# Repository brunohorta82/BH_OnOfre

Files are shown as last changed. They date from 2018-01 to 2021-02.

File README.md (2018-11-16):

# BH OnOfre
 
* [Intro](#id1)
* [Hardware](#id2)
* [Firmware](https://github.com/brunohorta82/easy_iot)
* [Video Tutoriais - YouTube](https://www.youtube.com/watch?v=OZenBfHWtak&list=PLxDLawCWayzDqAgOpIDJ-DHFAXYd_S-pr)
* [Donativos](#id6)
* [Site Oficial](http://bhonofre.pt/)

## Intro 
O projeto BH OnOfre, é uma solução IoT baseada em ESP8266 com o objetivo de tornar a automação domiciliar muito mais simples, de forma aberta e sem restrições. Todo o código fonte é aberto bem como Hardware.

**BH OnOfre Easy Light** é um dispositivo baseado em ESP8266 com 2 relés de estado sólido cada um de 2A, este permite controlar até 2 circuitos de iluminação independentes. O facto de possuir relés de estado sólido permite ligar e desligar luzes de forma silênciosa.
O OnOfre pode ser instalado atrás dos interruptores normais, possui conectores para ligar o interruptor normal, ou sensor touch. Para alem dos conectores dedicados, permite ainda ligar os mais diversos sensores/atuadores aos GPIO's disponiveis. 
O controlo do mesmo pode ser efectuado via Web, MQTT ou manualmente pelo interruptor, tem integração automatica com o Home Assistant.
Mais info em [Easy Light REPO](https://github.com/brunohorta82/BH_OnOfre/tree/master/OnOfre%20EasyLight)

## Bibliotecas necessárias 

Nome | Link | Versão 
:---: | :---: | ---:
JustWifi | [GIT](https://github.com/xoseperez/justwifi) | `last`
Timming | [GIT](https://github.com/scargill/Timing) | `last`
Async Mqtt Client | [GIT](https://github.com/marvinroger/async-mqtt-client) | `last`
ESP Async TCP | [GIT](https://github.com/me-no-dev/ESPAsyncTCP)| `last`
ESP Async Webserver | [GIT](https://github.com/me-no-dev/ESPAsyncWebServer) | `last`
Bounce2 | [GIT](https://github.com/thomasfredericks/Bounce2) | `last`
DHT Async | [GIT](https://github.com/brunohorta82/DHT_nonblocking) | `last`
Arduino Json | [ARDUINO IDE](https://arduinojson.org) | `5.*`

## Painel de Controlo 

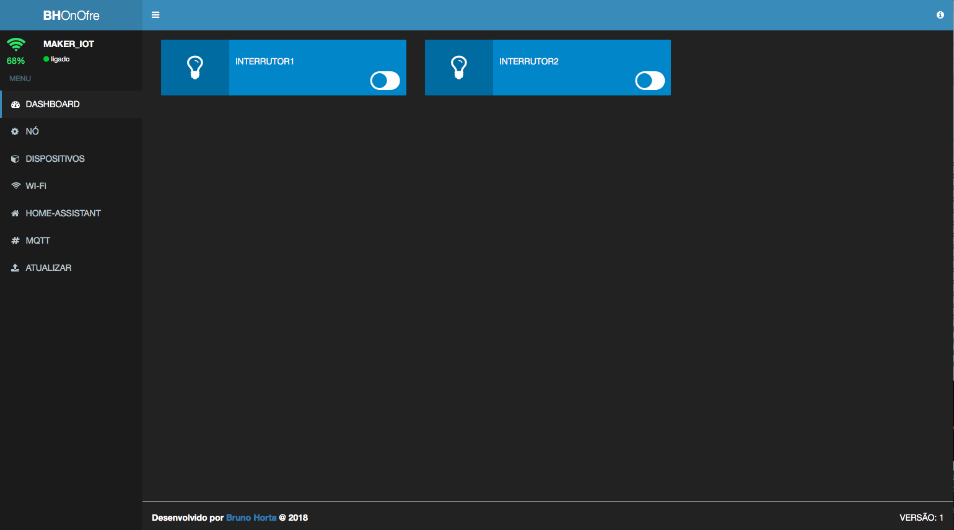
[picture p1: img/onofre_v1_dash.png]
dash

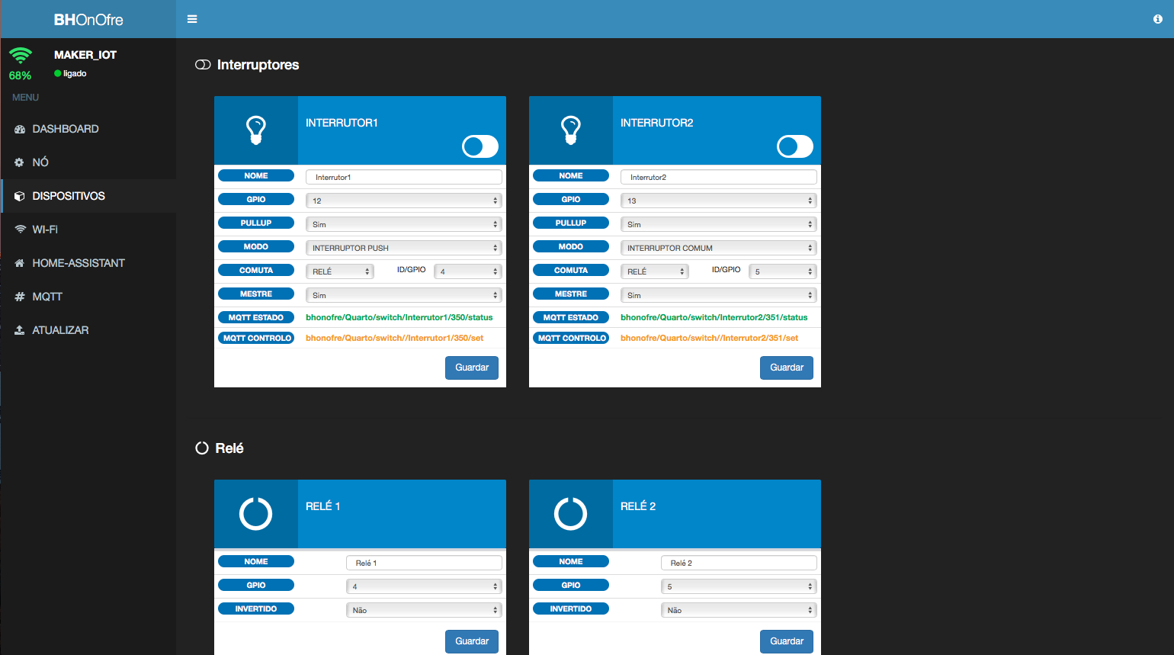
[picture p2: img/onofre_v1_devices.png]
devices


## Hardware 
* BH OnOfre Dev Board 3.4
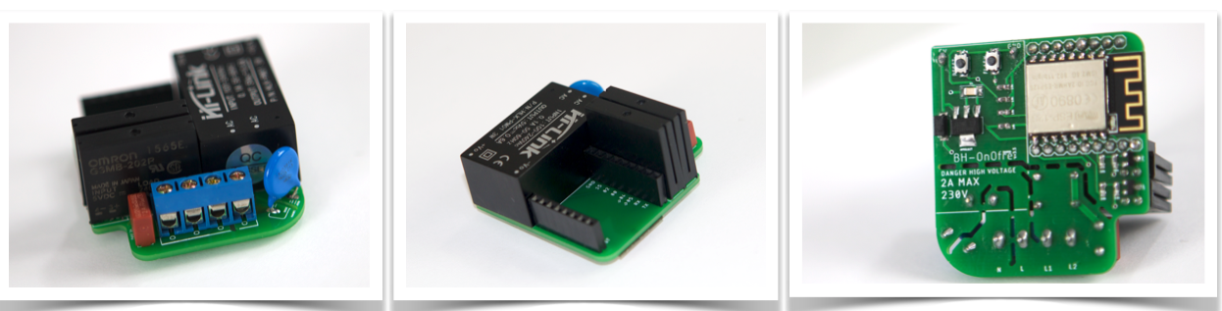
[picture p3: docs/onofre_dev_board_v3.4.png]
dev_board_3.4


## Software necessário 

- Arduino Ide (caso seja para alterar o codigo fonte)
- Upload do Firmware para o ESP8266 (dentro de cada projeto o firmware está dentro da pasta binarios)
- Aceder ao AP `SSID:BH_ONFFRE_NODE_ID` e configurar a Rede Wi-Fi
- Navegar até  `http://<bh-onofre name>.local` ou `http://<bh-onofre IP address>` ou `http://192.168.4.1` ligado directamente ao módulo
- Configurar o `Wi-Fi broker`, `MQTT broker` entre outras coisas como integração automática com `Home Assistant`
- E tá feito, agora é só curtir :) 

## Caixas e Adaptadores
 - [Onofre Livolo Powered by Michaël Memeteau](https://cad.onshape.com/documents/edaf7fef18d999cab7aa6aff/w/efbde367d3f13fc563e8fda8/e/a555c81f28f9aefdf7ebc964)
 - [Onofre Protecção Eléctrica Powered by Bruno Horta](https://cad.onshape.com/documents/2658804f4fec38f38b567684/w/01661975a7b4ba3d280e6216/e/88d1bd909d651dac55006571)

## Donativos 

Se gostaste do projeto podes fazer o teu donativo :).



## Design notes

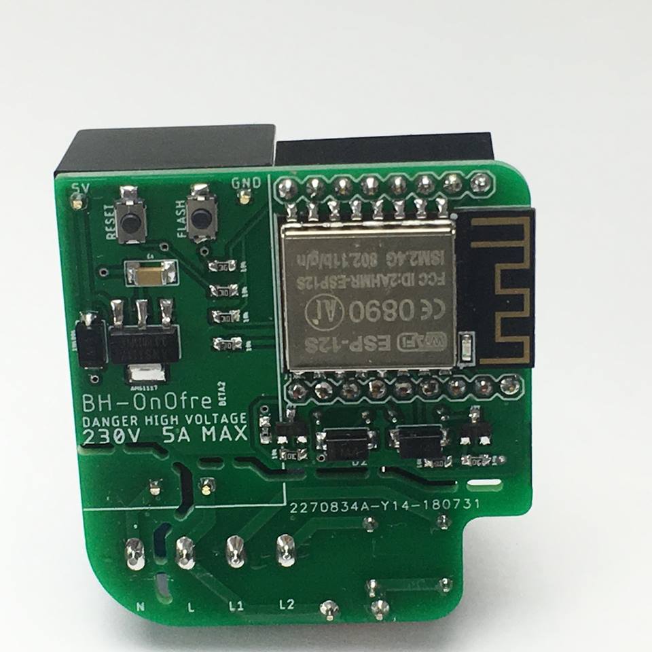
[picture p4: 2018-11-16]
docs/Onofre_5A_beta2_btm.jpg

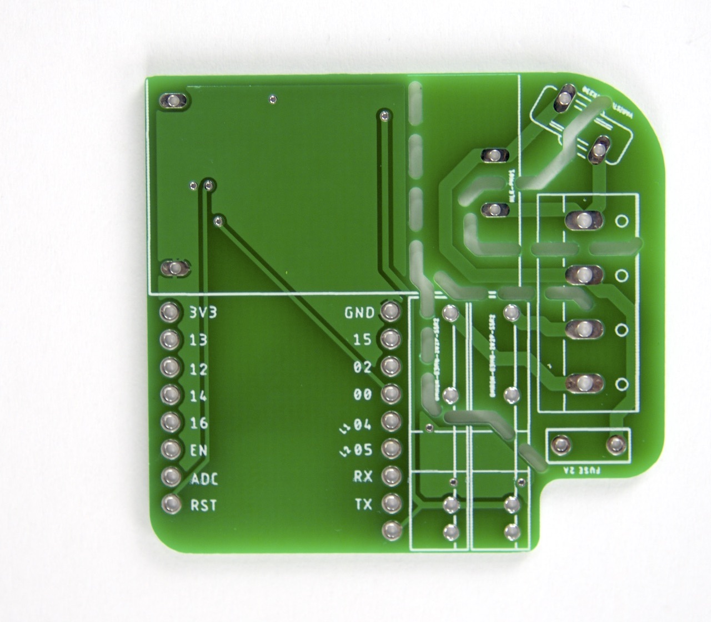
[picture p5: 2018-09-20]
docs/OnOfre_Dev_Board_Rev4.0_02.jpg

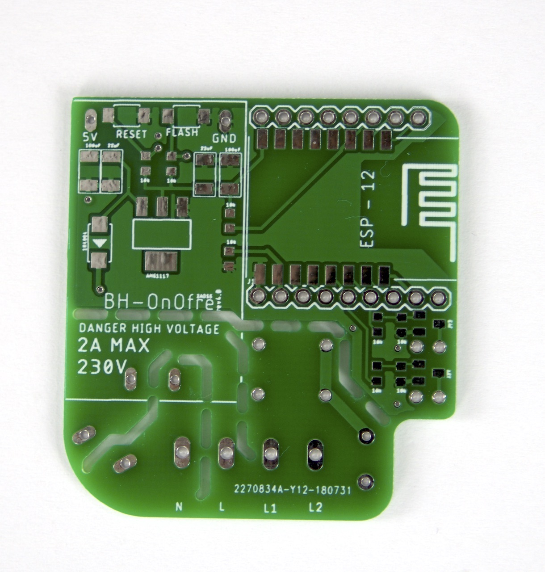
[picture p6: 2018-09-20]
docs/OnOfre_Dev_Board_Rev4.0_01.jpg

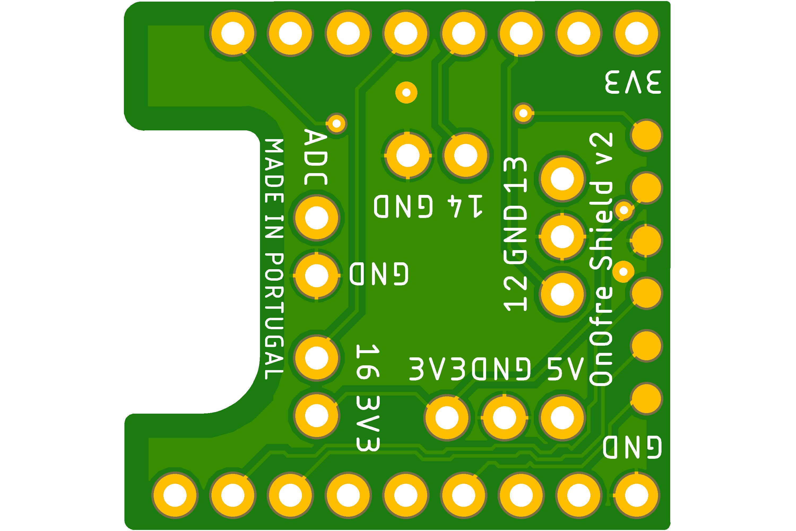
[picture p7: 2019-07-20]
PCB/ONOFRE_WIRE_SHIELD_v2/ONOFRE_WIRE_SHIELD_BTM.png

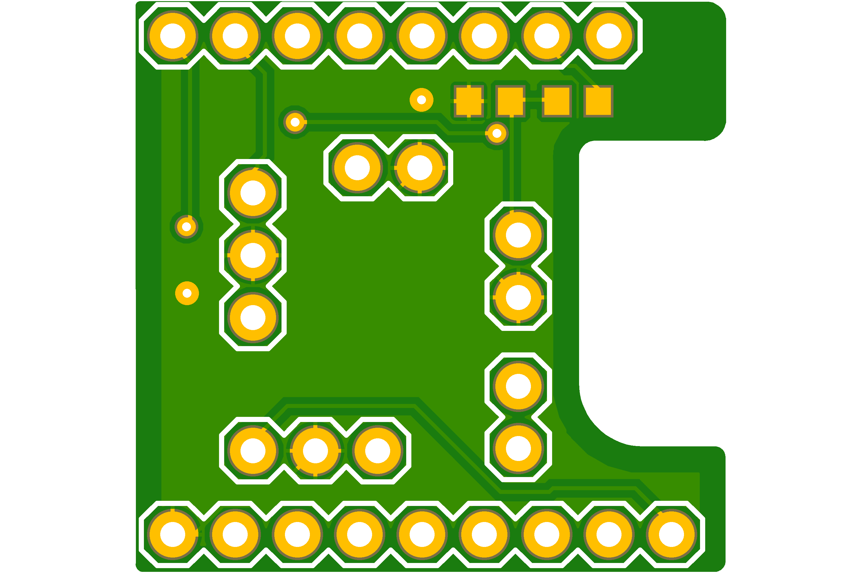
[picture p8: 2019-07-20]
PCB/ONOFRE_WIRE_SHIELD_v2/ONOFRE_WIRE_SHIELD_TOP.png

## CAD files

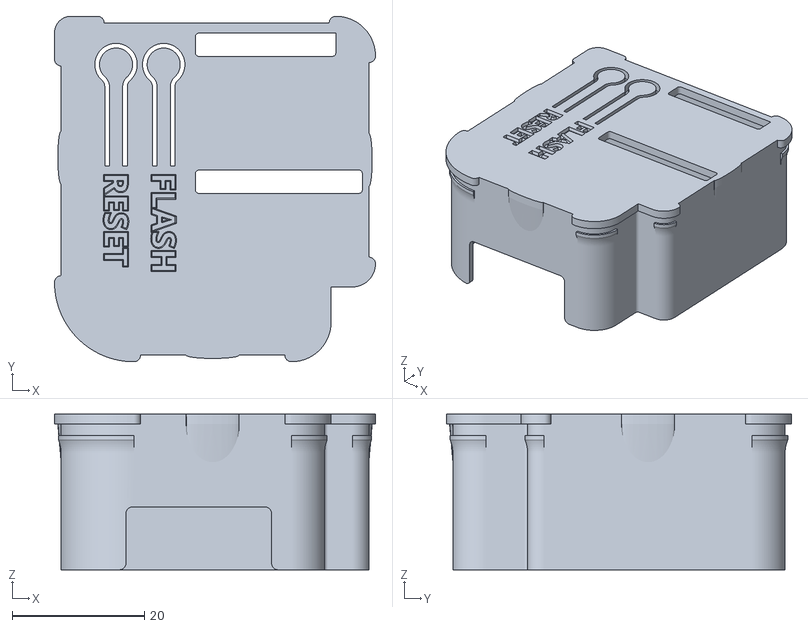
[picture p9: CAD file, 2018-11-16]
CAIXAS_CASES/Onofre Livolo/3D Printed BH Casing Livolo - Casing.stl
48.5 x 52.2 x 23.5

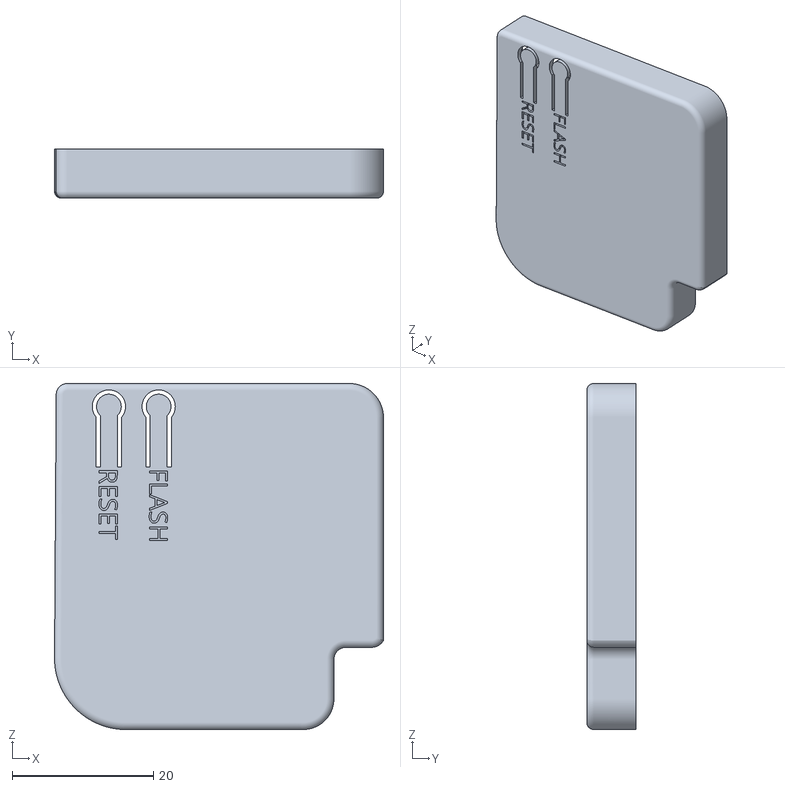
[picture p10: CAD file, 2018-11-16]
CAIXAS_CASES/Onofre Prot/Onofre Protecção.stl
46.6 x 7.00 x 49.0

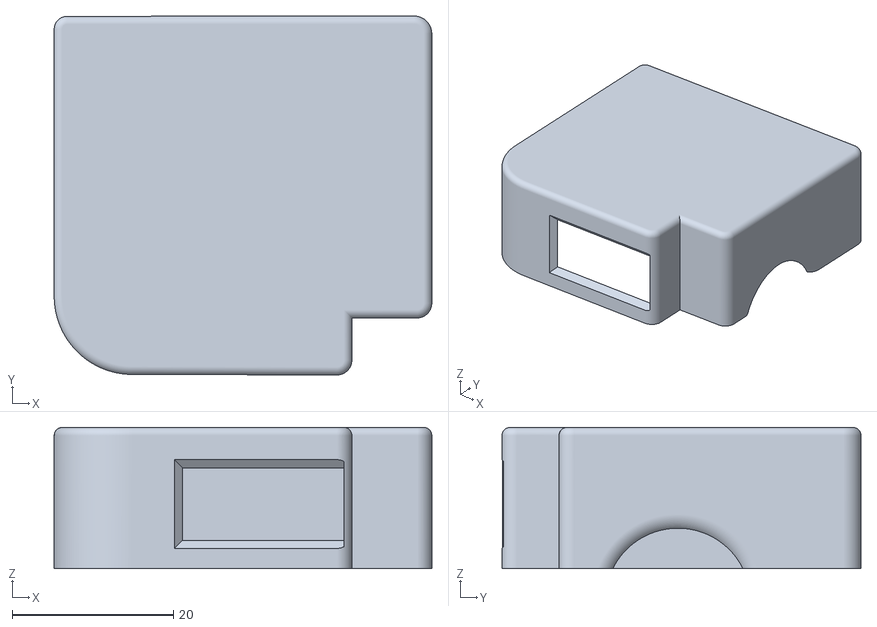
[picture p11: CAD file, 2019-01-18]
CAIXAS_CASES/Onofre Rev5/ONOFRE REV5.stl
46.8 x 44.5 x 17.5

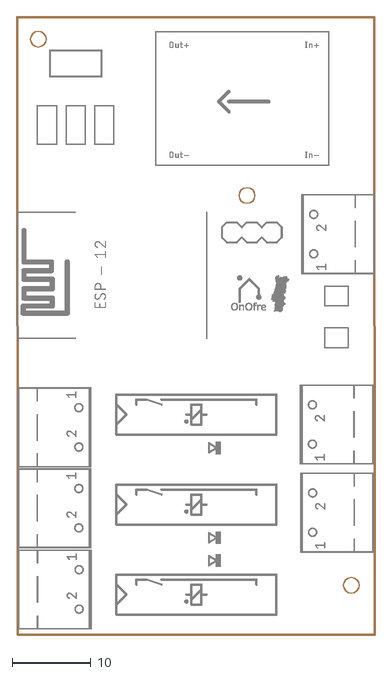
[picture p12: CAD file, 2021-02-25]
PCB/ONOFRE GATE/gate.dxf
45.7 x 78.6

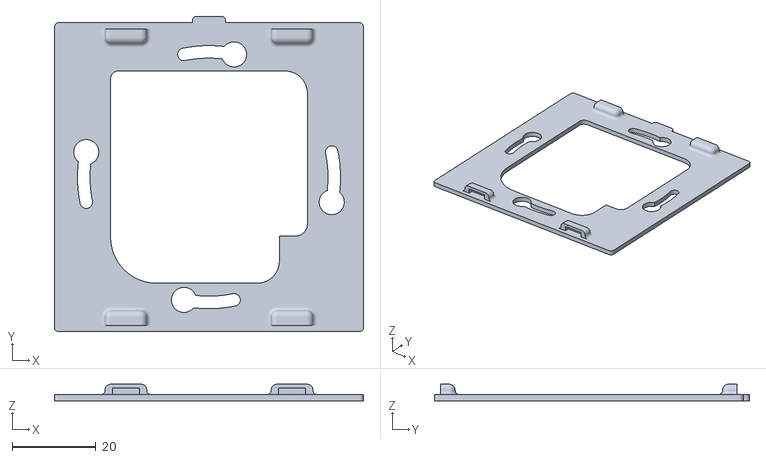
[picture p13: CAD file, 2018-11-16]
CAIXAS_CASES/Onofre Livolo/3D Printed BH Casing Livolo- Plate.stl
74.0 x 75.5 x 4.00

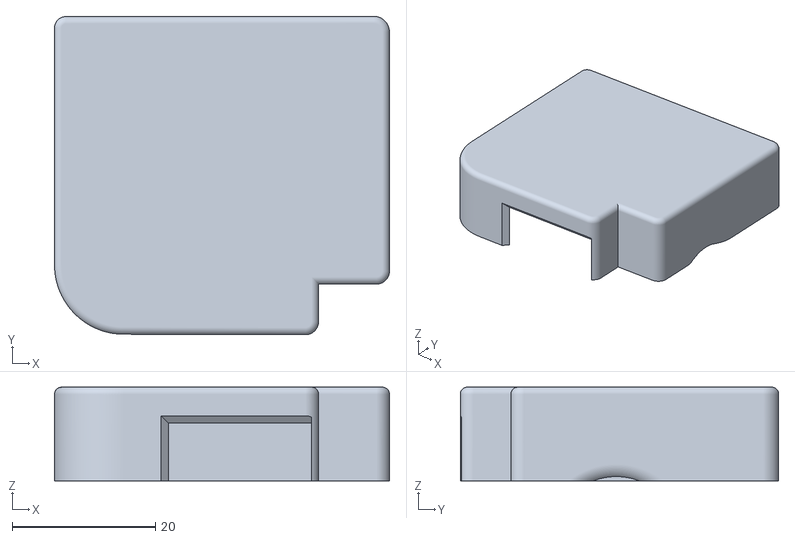
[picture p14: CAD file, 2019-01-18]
CAIXAS_CASES/Onofre Rev5/ONOFRE Bottom Cover REV5.stl
46.8 x 44.5 x 13.1

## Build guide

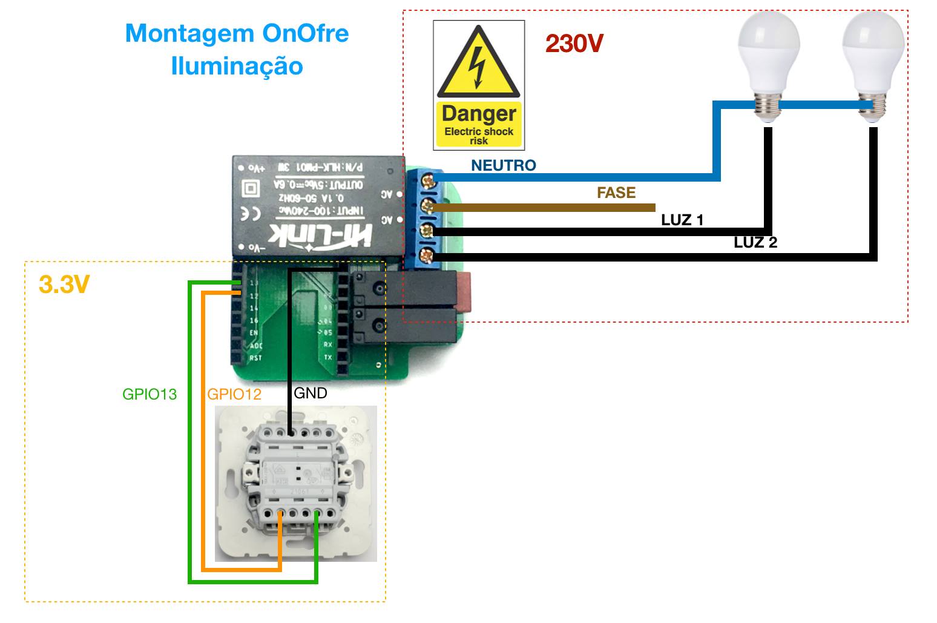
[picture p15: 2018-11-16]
docs/Montagem com iluminação.jpg

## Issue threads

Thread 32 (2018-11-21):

Controlo SSR

LuisCRSousa, 2018-11-21:
Pelo circuito estás a guiar-te pelo hFE do transistor e pelo drop em D3 para definir a corrente do LED, o que é uma má pratica e pode dar maus resultados.

O hFE muda drasticamente em diferentes batchs, temperaturas etc e muito facilmente colocas o LED com o dobro da corrente ou mais.

Recomendações
- Coloca o transistor a funcionar em modo saturação
- Adiciona resistência em série ao LED do SSR para definir a tua corrente e considera Vce=0
- Eliminar D3
- Podes eliminar R2 e R3
- Calcular novos valor de R1 para saturar o transistor

brunohorta82, 2018-11-21:
Olá Luis, obrigado pelos concelhos, na Rev5 já tinha retirado o D3, agora em relação as resistências sendo apenas uma em Serie para cada relé não terei problemas em ter 2 transistores em paralelo sem as resistências de pullup/pulldown?
Já agora que valores recomendas?

Em relação a  maus resultados não tem acontecido em testes de usabilidade diária com mais de ano e meio de uso

LuisCRSousa, 2018-11-21:
Se o GPIO04 e 05 nunca estiverem em alta impedância não há qualquer problema em retirar a R3 e R4. Caso contrário, ou como garantia, podes deixar.

Para a resistência em série com cada LED pode ser uma de 400R o que coloca no máximo uma corrente de 10mA e já fica protegido para qualquer situação estranha como hFE.

Para as R3, R4, R2 e R1 , fiz os cálculos com os valores que já tens e até nem é preciso tocar. Esses valores coloca uma corrente de 0.3mA pela base dos transistors, e com o hFE mínimo definido pelo datasheet, e impõe uma corrente 12mA no coletor. Como a nova resistência de 400 impõe no máximo 10mA ficas garantido para qualquer variação do hFE.

Uma boa prática é calcular o circuito com o hFE para os piores/melhores casos. Com a resistência de 400R garantes que por muito que o hFE aumente, a corrente do LED tem o máximo de 10mA.

brunohorta82, 2018-11-21:
Ok então recomendas 400R no LED do SSR :), Oki, vou colocar

LuisCRSousa, 2018-11-22:
Sim :)

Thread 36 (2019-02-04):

Interrutor vs Interruptor

Ironicster, 2019-02-04:
`     switchJson(id1,SWITCH_ONE,0,0,RELAY_TYPE,RELAY_ONE,0,0,INIT_STATE_OFF,  "Interruptor1", BUTTON_SET_PULLUP,INIT_STATE_OFF,  BUTTON_SWITCH, BUTTON_MASTER, MQTT_STATE_TOPIC_BUILDER(id1,SWITCH_DEVICE,"Interrutor1"), MQTT_COMMAND_TOPIC_BUILDER(id1,SWITCH_DEVICE,"Interruptor1"), "light");
      switchJson(id2,SWITCH_TWO,0,0,RELAY_TYPE,RELAY_TWO,0,0, INIT_STATE_OFF, "Interruptor2", BUTTON_SET_PULLUP,INIT_STATE_OFF,  BUTTON_SWITCH, BUTTON_MASTER, MQTT_STATE_TOPIC_BUILDER(id2,SWITCH_DEVICE,"Interrutor2"),MQTT_COMMAND_TOPIC_BUILDER(id2,SWITCH_DEVICE,"Interruptor2"), "light");`

LInha 447 do Switches.ino
Está Interrutor em vez de Interruptor.
Engano?

brunohorta82, 2019-07-07:
PT: Obrigado está corrigido :)
EN: thanks I already fix that :)

Closed 2019-07-07.

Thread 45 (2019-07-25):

Any plans to make one with 3 relays?

hobojoe, 2019-07-25:
Hi, first of all, great project! Really well done!

I would like to know if you have any plans to make a similar board with 3 relays?

It would be very good for places such as Brazil, where we have 3 switches in 1 gang box.

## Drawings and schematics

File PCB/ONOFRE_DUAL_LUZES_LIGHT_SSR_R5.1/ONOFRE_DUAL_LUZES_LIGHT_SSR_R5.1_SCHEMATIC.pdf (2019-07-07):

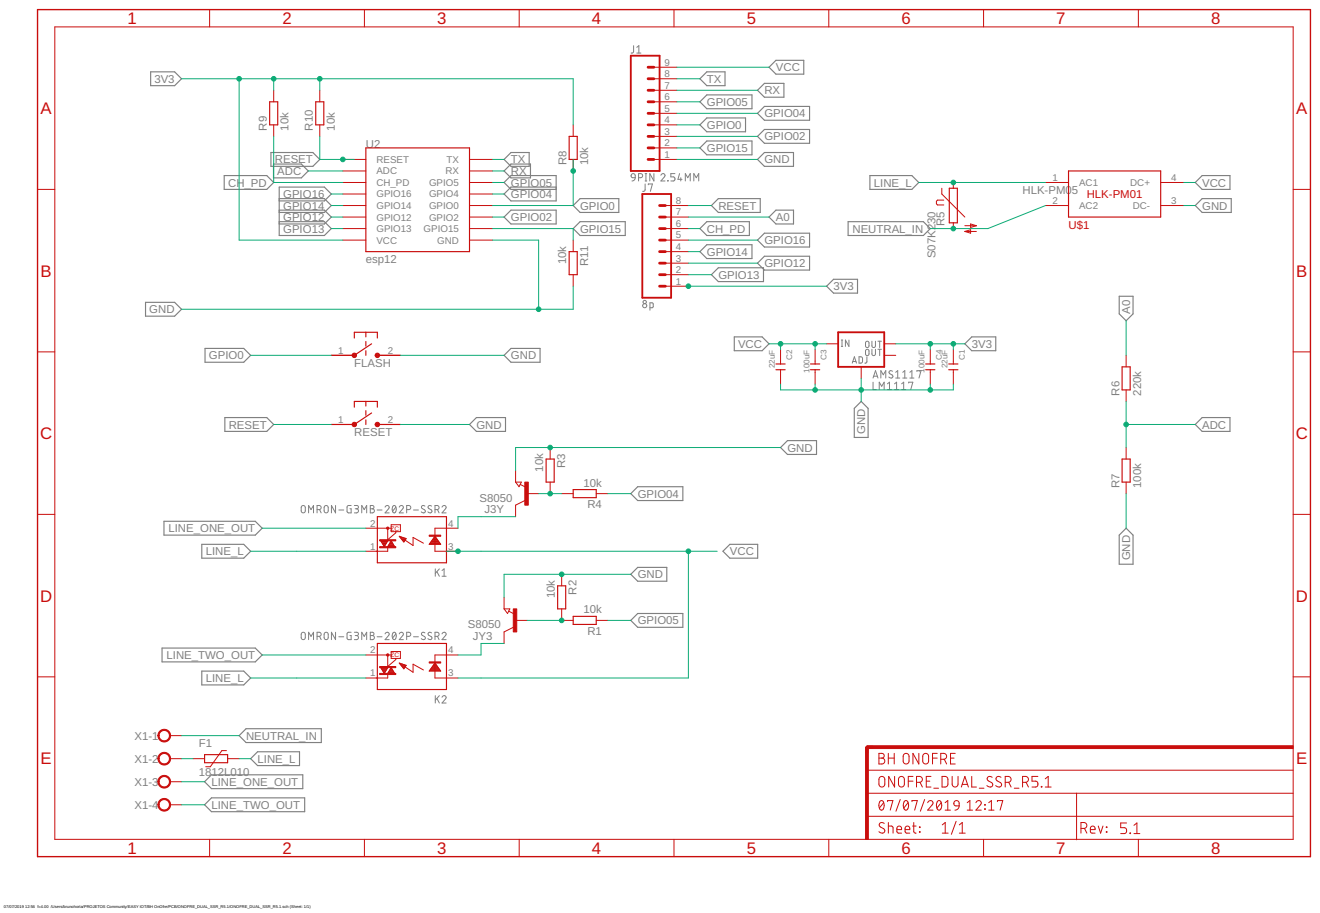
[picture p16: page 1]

07/07/2019 12:56 f=4.00 /Users/brunohorta/PROJETOS Community/EASY IOT/BH OnOfre/PCB/ONOFRE_DUAL_SSR_R5.1/ONOFRE_DUAL_SSR_R5.1.sch (Sheet: 1/1)

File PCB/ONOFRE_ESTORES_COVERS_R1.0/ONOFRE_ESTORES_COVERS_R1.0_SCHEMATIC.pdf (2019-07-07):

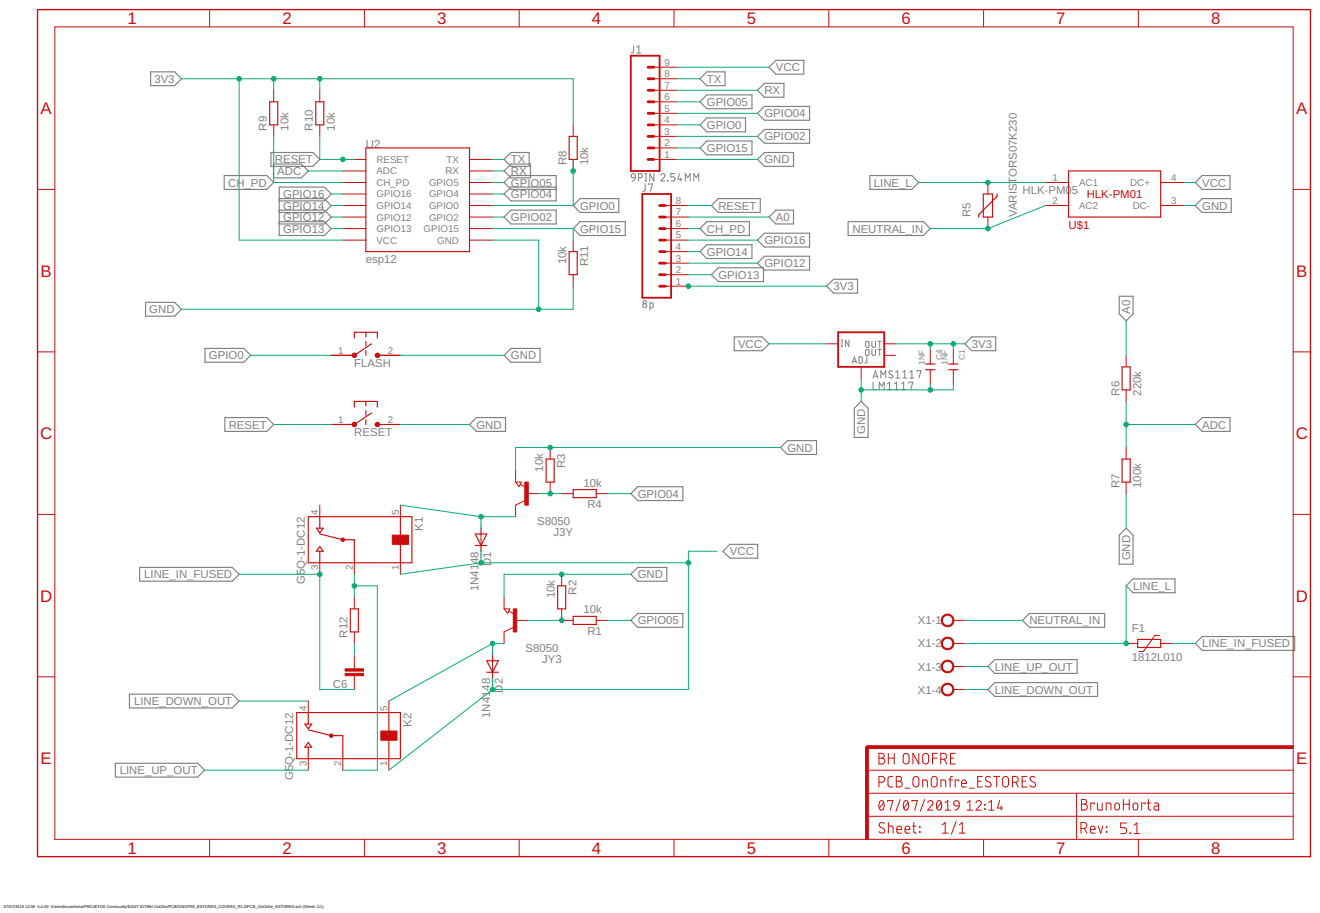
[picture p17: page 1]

SpiceOrder 1 SpiceOrder 2 SpiceOrder 1 SpiceOrder 2 S8050

07/07/2019 12:59 f=4.00 /Users/brunohorta/PROJETOS Community/EASY IOT/BH OnOfre/PCB/ONOFRE_ESTORES_COVERS_R1.0/PCB_OnOnfre_ESTORES.sch (Sheet: 1/1)

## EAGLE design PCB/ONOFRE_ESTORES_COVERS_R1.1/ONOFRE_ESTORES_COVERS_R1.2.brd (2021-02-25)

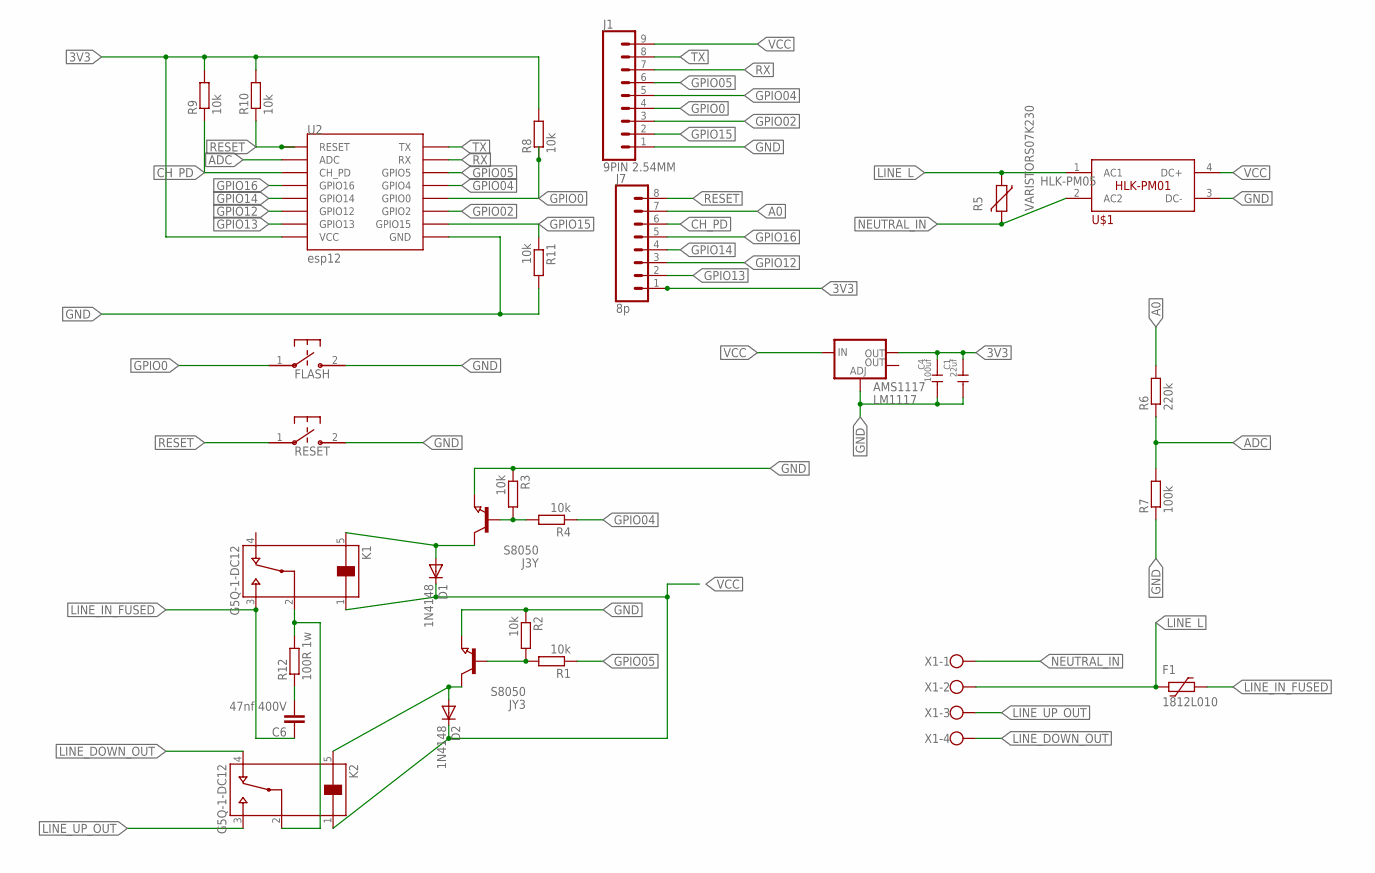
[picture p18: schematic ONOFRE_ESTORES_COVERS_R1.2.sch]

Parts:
AMS1117: LM1117; SOT223
C1: 22uf; C1206
C4: 100uf; C1206
C6: 47nf 400V; C102-043X133
D1, D2: 1N4148; SOD80C
F1: 1812L010; 1812L
FLASH: B3U-1000P-2P-SMD; B3U-1000P
J1: 9PIN 2.54MM; 1X09
J3Y: S8050; SOT23
J7: 8p; 1X08
JY3: S8050; SOT23
K1, K2: G5Q-1-DC12; RELAY_G5Q-1-DC12
R1, R2, R3, R4, R8, R9, R10, R11: 10k; R0603
R5: VARISTORS07K230; S07K230
R6: 220k; R0603
R7: 100k; R0603
R12: 100R 1w; R2512
RESET: B3U-1000P-2P-SMD; B3U-1000P
U2: esp12; ESP12-SMD
U$1: HLK-PM01
X1: W237-4

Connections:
3V3: AMS1117.2 (OUT), C1.1, C4.1, J7.1, R8.2, R9.2, R10.2, U2.VCC
A0: J7.7, R6.2
ADC: R6.1, R7.2, U2.ADC
CH_PD: J7.6, R9.1, U2.CH_PD
GND: AMS1117.1 (ADJ), C1.2, C4.2, FLASH.2, J1.1, J3Y.2 (E), JY3.2 (E), R2.1, R3.1, R7.1, R11.2, RESET.2, U2.GND, U$1.3 (DC-)
GPIO0: FLASH.1, J1.4, R8.1, U2.GPIO0
GPIO02: J1.3, U2.GPIO2
GPIO04: J1.5, R4.1, U2.GPIO4
GPIO05: J1.6, R1.1, U2.GPIO5
GPIO12: J7.3, U2.GPIO12
GPIO13: J7.2, U2.GPIO13
GPIO14: J7.4, U2.GPIO14
GPIO15: J1.2, R11.1, U2.GPIO15
GPIO16: J7.5, U2.GPIO16
LINE_DOWN_OUT: K2.4, X1.4
LINE_IN_FUSED: C6.1, F1.1, K1.3
LINE_L: F1.2, R5.1, U$1.1 (AC1), X1.2
LINE_UP_OUT: K2.3, X1.3
unnamed: D1.A, J3Y.3 (C), K1.5
unnamed: K1.2, K2.2, R12.2
unnamed: C6.2, R12.1
unnamed: J3Y.1 (B), R3.2, R4.2
unnamed: D2.A, JY3.3 (C), K2.5
unnamed: JY3.1 (B), R1.2, R2.2
NEUTRAL_IN: R5.2, U$1.2 (AC2), X1.1
RESET: J7.8, R10.1, RESET.1, U2.RESET
RX: J1.7, U2.RXD0 (RX)
TX: J1.8, U2.TXD0 (TX)
VCC: AMS1117.3 (IN), D1.C, D2.C, J1.9, K1.1, K2.1, U$1.4 (DC+)

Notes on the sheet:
HLK-PM05

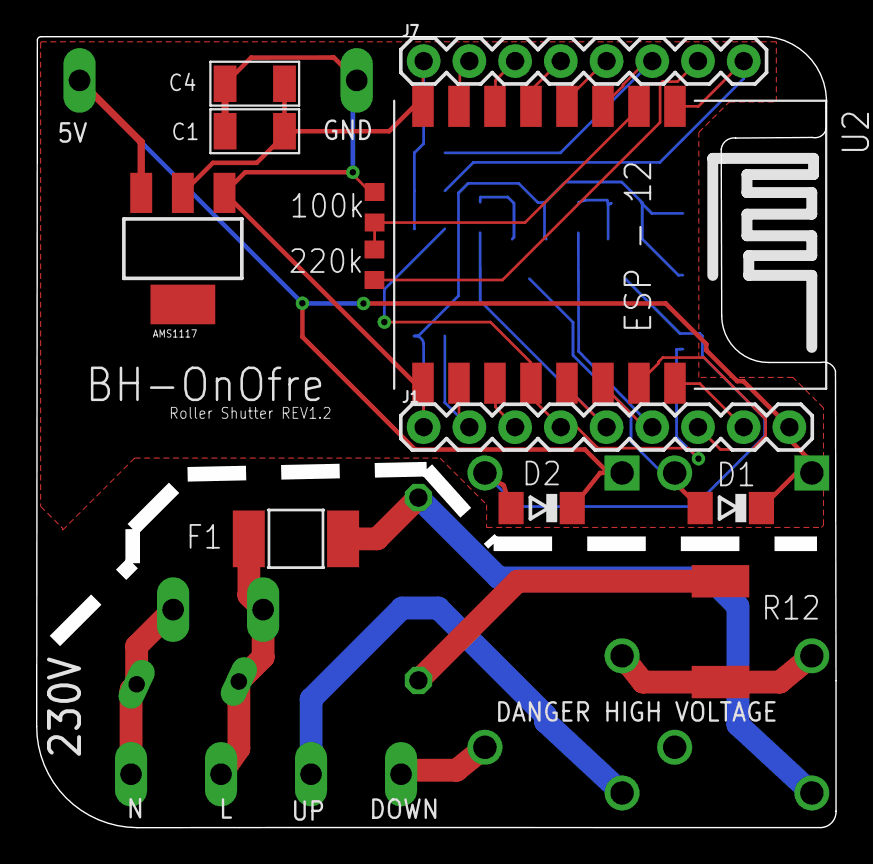
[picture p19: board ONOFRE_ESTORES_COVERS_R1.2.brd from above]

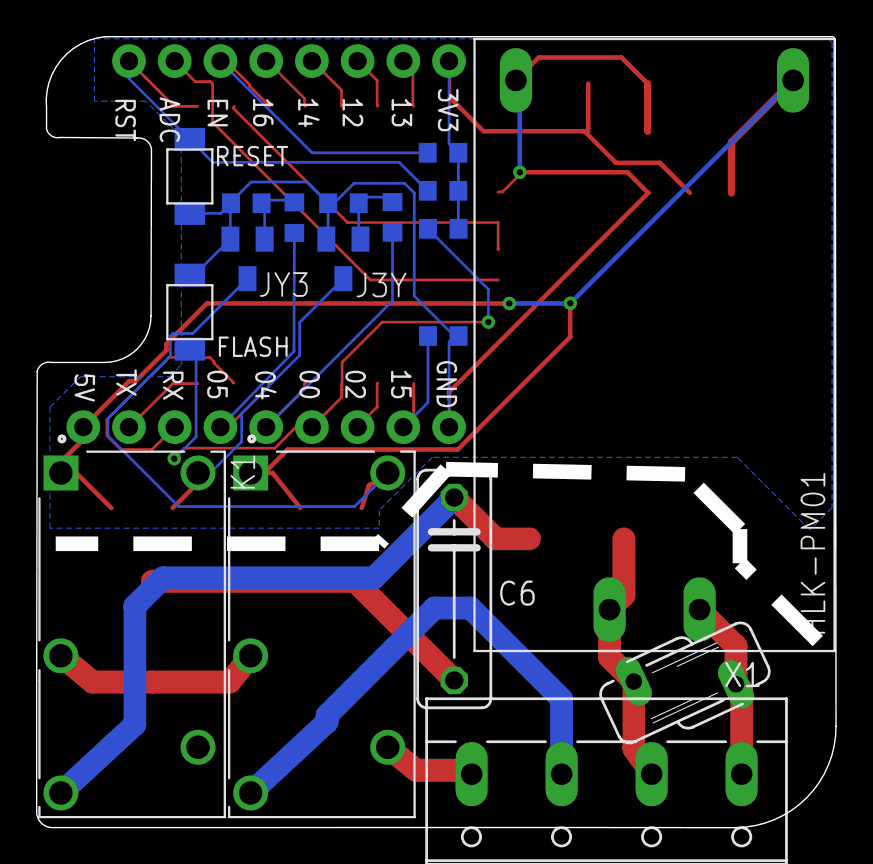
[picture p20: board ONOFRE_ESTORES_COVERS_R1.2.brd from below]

Board: 2 copper layers, 44.4 x 43.9 mm, 30 parts (18 on the bottom side), 29 nets.

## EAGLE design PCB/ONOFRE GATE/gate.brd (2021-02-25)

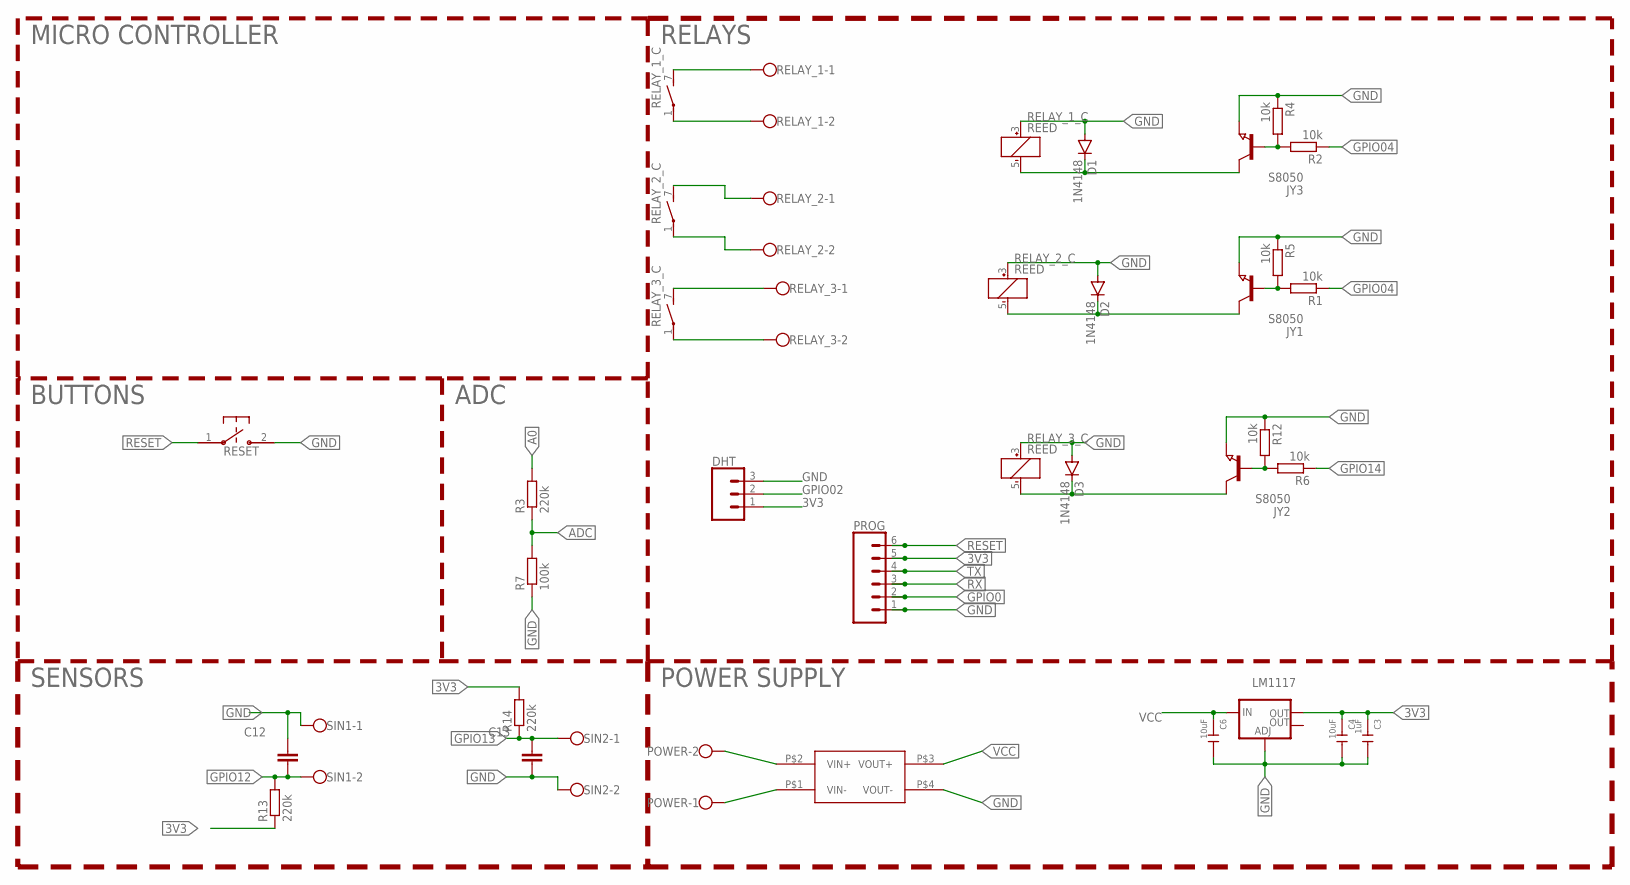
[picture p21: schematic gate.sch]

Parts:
AMS1117: LM1117; SOT223
C3: 1uF; C1206
C4, C6: 10uF; C1206
C12, C13: C-EUC0805; C0805
D1, D2, D3: 1N4148; SOD80C
DHT: CONN_03; 1X03
JY1, JY2, JY3: S8050; SOT23
POWER: W237-102
PROG: CONN_06NO_SILK_NO_POP; 1X06_NO_SILK
R1, R2, R4, R5, R6, R12: 10k; R0603
R3, R13, R14: 220k; R0603
R7: 100k; R0603
RELAY_1, RELAY_2, RELAY_3: W237-102
RELAY_1_C, RELAY_2_C, RELAY_3_C: REED
RESET: B3U-1000P-2P-SMD; B3U-1000P
SIN1, SIN2: W237-102
U$2: MP1584-MINI-SMDDL; MINI-DC-BRICK_DL-SMD

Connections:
3V3: AMS1117.2 (OUT), C3.1, C4.1, DHT.1, PROG.5, R13.1, R14.2
A0: R3.2
ADC: R3.1, R7.2
E: D1.C, JY3.3 (C), RELAY_1_C.5 (-)
F: D3.C, JY2.3 (C), RELAY_3_C.5 (-)
GND: AMS1117.1 (ADJ), C3.2, C4.2, C6.2, C12.1, C13.2, D1.A, D2.A, D3.A, DHT.3, JY1.2 (E), JY2.2 (E), JY3.2 (E), POWER.1, PROG.1, R4.1, R5.1, R7.1, R12.1, RELAY_1_C.3 (+), RELAY_2_C.3 (+), RELAY_3_C.3 (+), RESET.2, SIN1.1, SIN2.2, U$2.P$1 (VIN-), U$2.P$4 (VOUT-)
GND1: RELAY_1.1, RELAY_1_C.7 (S)
GND2: RELAY_2.1, RELAY_2_C.7 (S)
GND3: RELAY_3.1, RELAY_3_C.7 (S)
GPIO0: PROG.2
GPIO02: DHT.2
GPIO04: R1.1, R2.1
GPIO12: C12.2, R13.2, SIN1.2
GPIO13: C13.1, R14.1, SIN2.1
GPIO14: R6.1
unnamed: RELAY_1.2, RELAY_1_C.1
unnamed: RELAY_2.2, RELAY_2_C.1
unnamed: RELAY_3.2, RELAY_3_C.1
unnamed: JY1.1 (B), R1.2, R5.2
unnamed: JY2.1 (B), R6.2, R12.2
unnamed: JY3.1 (B), R2.2, R4.2
unnamed: POWER.2, U$2.P$2 (VIN+)
RESET: PROG.6, RESET.1
RX: PROG.3
T: D2.C, JY1.3 (C), RELAY_2_C.5 (-)
TX: PROG.4
VCC: AMS1117.3 (IN), C6.1, U$2.P$3 (VOUT+)

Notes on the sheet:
BUTTONS
MICRO CONTROLLER
ADC
RELAYS
POWER SUPPLY
SENSORS

Board: 2 copper layers, 35 parts (0 on the bottom side), 21 nets, no tracks yet.

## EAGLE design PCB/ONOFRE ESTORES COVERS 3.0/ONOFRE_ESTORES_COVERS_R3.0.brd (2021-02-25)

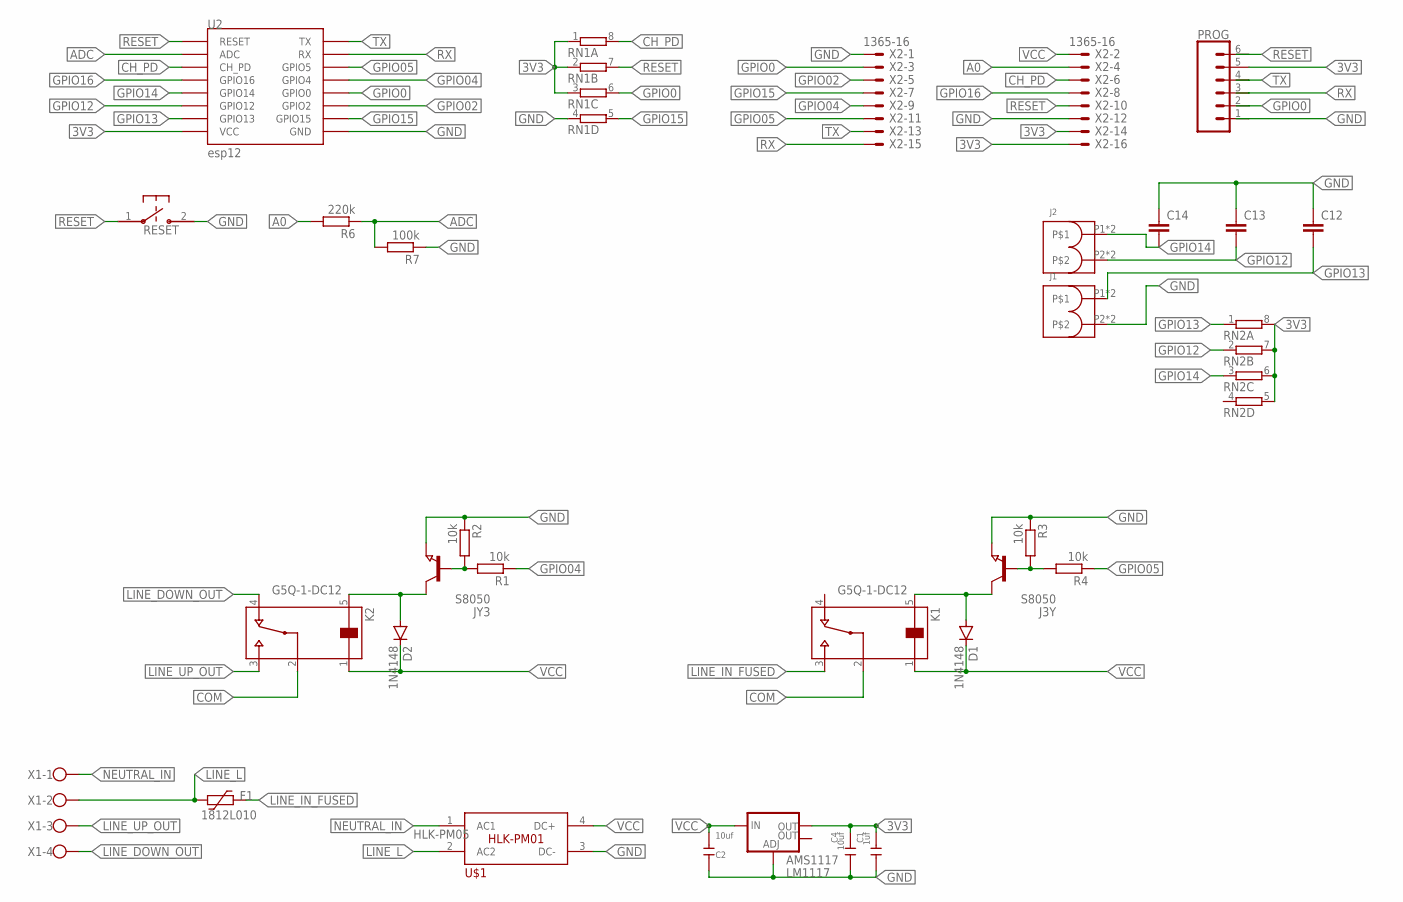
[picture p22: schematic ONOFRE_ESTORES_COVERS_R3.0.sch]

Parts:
AMS1117: LM1117; SOT223
C1: 1uf; C1206
C2, C4: 10uf; C1206
C12, C13, C14: C-EUC0805; C0805
D1, D2: 1N4148; SOD80C
F1: 1812L010; 1812L
J1, J2: 46.142.1001; P_46.142.1001
J3Y: S8050; SOT23
JY3: S8050; SOT23
K1, K2: G5Q-1-DC12; RELAY_G5Q-1-DC12
PROG: CONN_06NO_SILK_NO_POP; 1X06_NO_SILK
R1, R2, R3, R4: 10k; R0603
R6: 220k; R0603
R7: 100k; R0603
RESET: B3U-1000P-2P-SMD; B3U-1000P
RN1, RN2: 4R-N0603-ARV; 0603-ARV
U2: esp12; ESP12-SMD
U$1: HLK-PM01
X1: W237-4
X2: 1365-16

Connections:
3V3: AMS1117.2 (OUT), C1.1, C4.1, PROG.5, RN1.1, RN1.2 (1), RN1.3 (1), RN2.5 (2), RN2.6 (2), RN2.7 (2), RN2.8 (2), U2.VCC, X2.14, X2.16
A0: R6.2, X2.4
ADC: R6.1, R7.2, U2.ADC
CH_PD: RN1.8 (2), U2.CH_PD, X2.6
COM: K1.2, K2.2
GND: AMS1117.1 (ADJ), C1.2, C2.2, C4.2, C12.1, C13.1, C14.1, J1.P2, J1.P2.1, J3Y.2 (E), JY3.2 (E), PROG.1, R2.1, R3.1, R7.1, RESET.2, RN1.4 (1), U2.GND, U$1.3 (DC-), X2.1, X2.12
GPIO0: PROG.2, RN1.6 (2), U2.GPIO0, X2.3
GPIO02: U2.GPIO2, X2.5
GPIO04: R1.1, U2.GPIO4, X2.9
GPIO05: R4.1, U2.GPIO5, X2.11
GPIO12: C13.2, J2.P2, J2.P2.1, RN2.2 (1), U2.GPIO12
GPIO13: C12.2, J1.P1, J1.P1.1, RN2.1, U2.GPIO13
GPIO14: C14.2, J2.P1, J2.P1.1, RN2.3 (1), U2.GPIO14
GPIO15: RN1.5 (2), U2.GPIO15, X2.7
GPIO16: U2.GPIO16, X2.8
LINE_DOWN_OUT: K2.4, X1.4
LINE_IN_FUSED: F1.1, K1.3
LINE_L: F1.2, U$1.2 (AC2), X1.2
LINE_UP_OUT: K2.3, X1.3
unnamed: D1.A, J3Y.3 (C), K1.5
unnamed: J3Y.1 (B), R3.2, R4.2
unnamed: D2.A, JY3.3 (C), K2.5
unnamed: JY3.1 (B), R1.2, R2.2
NEUTRAL_IN: U$1.1 (AC1), X1.1
RESET: PROG.6, RESET.1, RN1.7 (2), U2.RESET, X2.10
RX: PROG.3, U2.RXD0 (RX), X2.15
TX: PROG.4, U2.TXD0 (TX), X2.13
VCC: AMS1117.3 (IN), C2.1, D1.C, D2.C, K1.1, K2.1, U$1.4 (DC+), X2.2

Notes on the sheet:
HLK-PM05

Board: 2 copper layers, 31 parts (6 on the bottom side), 28 nets, no tracks yet.

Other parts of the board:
U$2: DANGE_HIGH_VOLTAGE_MEDIUM

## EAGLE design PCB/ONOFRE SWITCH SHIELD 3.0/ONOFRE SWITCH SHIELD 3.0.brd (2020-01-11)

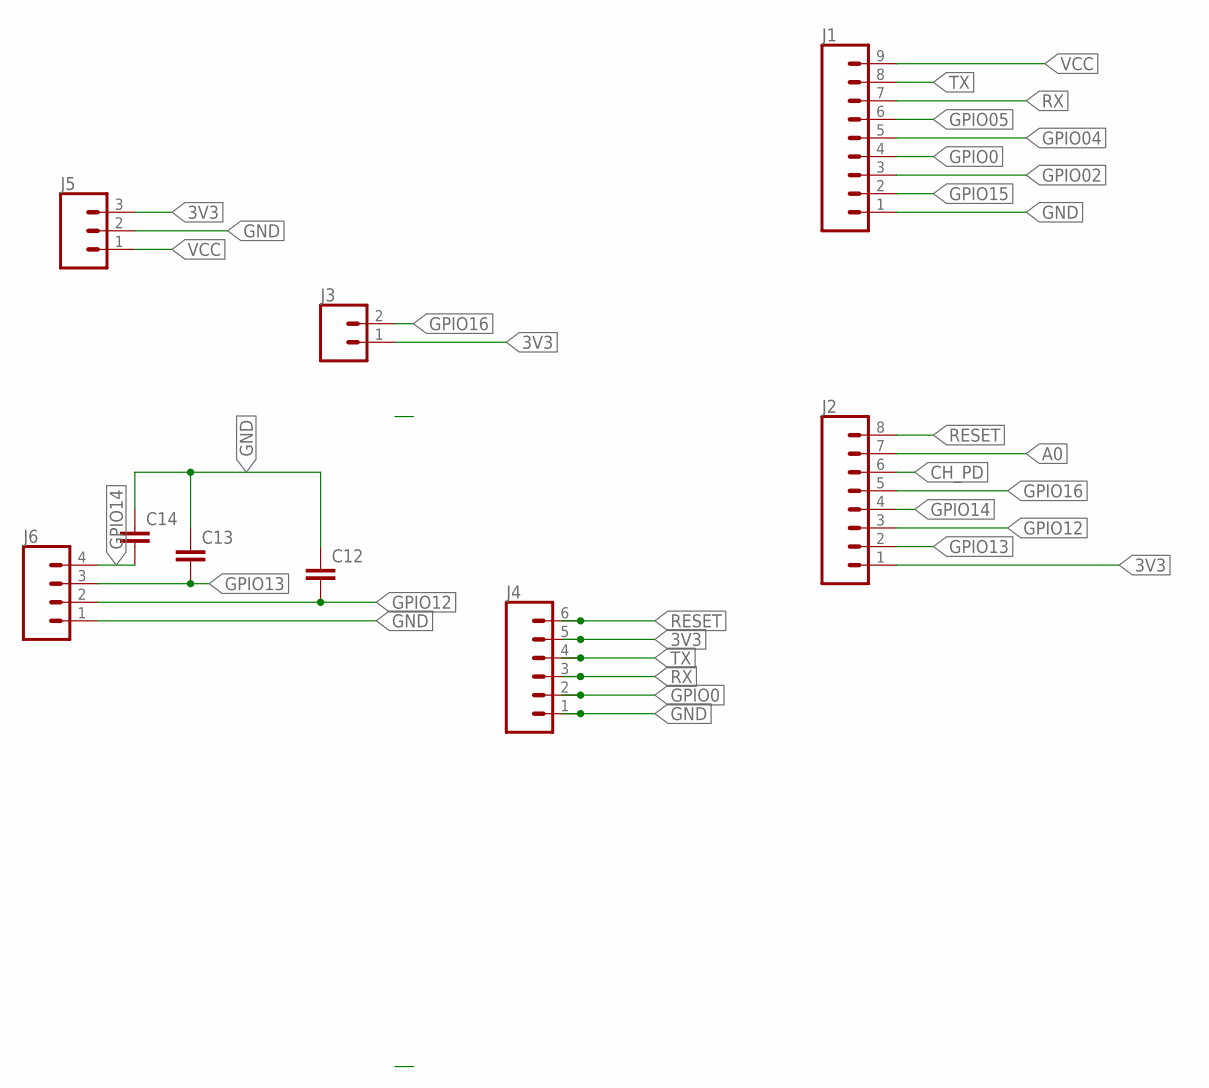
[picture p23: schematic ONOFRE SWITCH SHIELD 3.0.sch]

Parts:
C12, C13, C14: C-EUC0805; C0805
J1: CONN_09; 1X09
J2: CONN_08"; 1X08
J3: CONN_02; 1X02
J4: CONN_06NO_SILK_NO_POP; 1X06_NO_SILK
J5: CONN_03; 1X03
J6: CONN_04; 1X04

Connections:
3V3: J2.1, J3.1, J4.5, J5.3
A0: J2.7
CH_PD: J2.6
GND: C12.1, C13.1, C14.1, J1.1, J4.1, J5.2, J6.1
GPIO0: J1.4, J4.2
GPIO02: J1.3
GPIO04: J1.5
GPIO05: J1.6
GPIO12: C12.2, J2.3, J6.2
GPIO13: C13.2, J2.2, J6.3
GPIO14: C14.2, J2.4, J6.4
GPIO15: J1.2
GPIO16: J2.5, J3.2
RESET: J2.8, J4.6
RX: J1.7, J4.3
TX: J1.8, J4.4
VCC: J1.9, J5.1

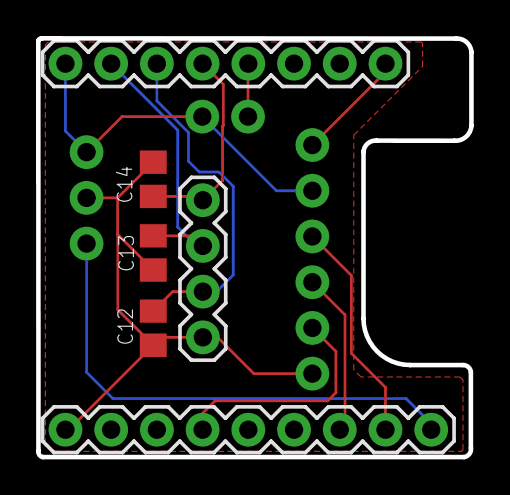
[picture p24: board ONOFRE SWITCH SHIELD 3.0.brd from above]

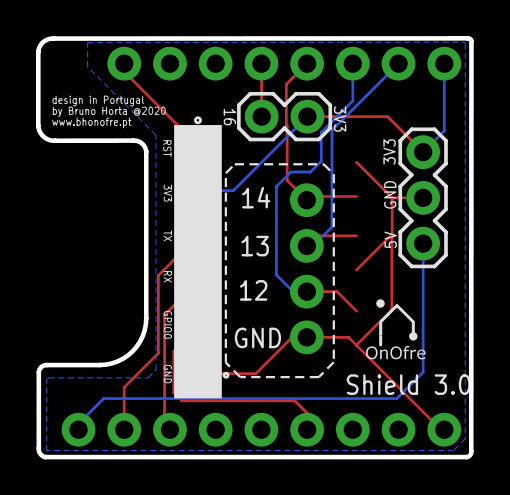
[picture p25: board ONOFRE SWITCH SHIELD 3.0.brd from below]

Board: 2 copper layers, 24.1 x 23.3 mm, 9 parts (2 on the bottom side), 11 nets.

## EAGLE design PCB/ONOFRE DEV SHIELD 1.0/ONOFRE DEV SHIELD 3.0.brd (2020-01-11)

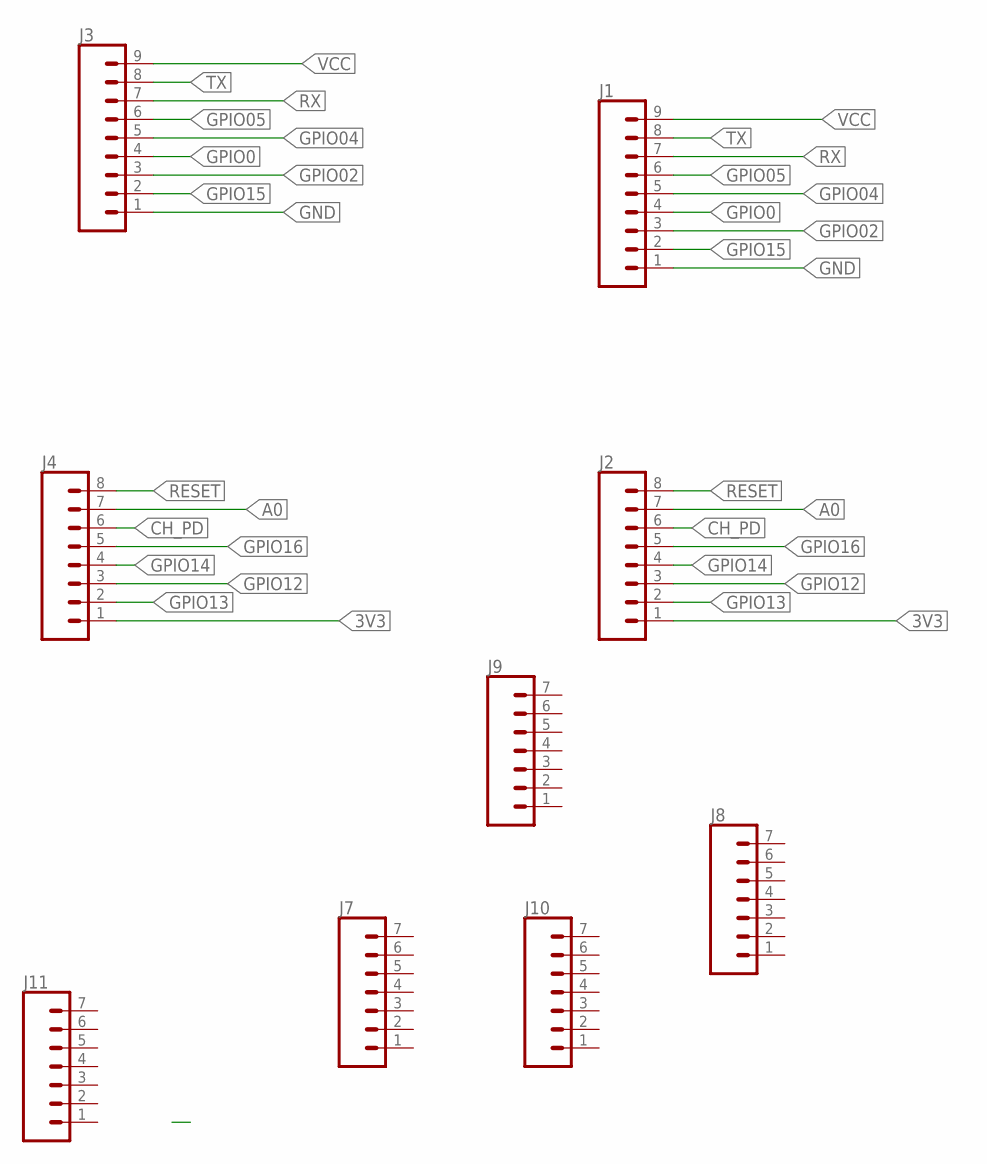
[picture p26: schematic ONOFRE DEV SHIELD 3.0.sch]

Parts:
J1, J3: CONN_09; 1X09
J2, J4: CONN_08"; 1X08
J7, J8, J9, J10, J11: CONN_07NO_SILK; 1X07_NO_SILK

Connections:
3V3: J2.1, J4.1
A0: J2.7, J4.7
CH_PD: J2.6, J4.6
GND: J1.1, J3.1
GPIO0: J1.4, J3.4
GPIO02: J1.3, J3.3
GPIO04: J1.5, J3.5
GPIO05: J1.6, J3.6
GPIO12: J2.3, J4.3
GPIO13: J2.2, J4.2
GPIO14: J2.4, J4.4
GPIO15: J1.2, J3.2
GPIO16: J2.5, J4.5
RESET: J2.8, J4.8
RX: J1.7, J3.7
TX: J1.8, J3.8
VCC: J1.9, J3.9

Board: 2 copper layers, 9 parts (2 on the bottom side), 17 nets, no tracks yet.

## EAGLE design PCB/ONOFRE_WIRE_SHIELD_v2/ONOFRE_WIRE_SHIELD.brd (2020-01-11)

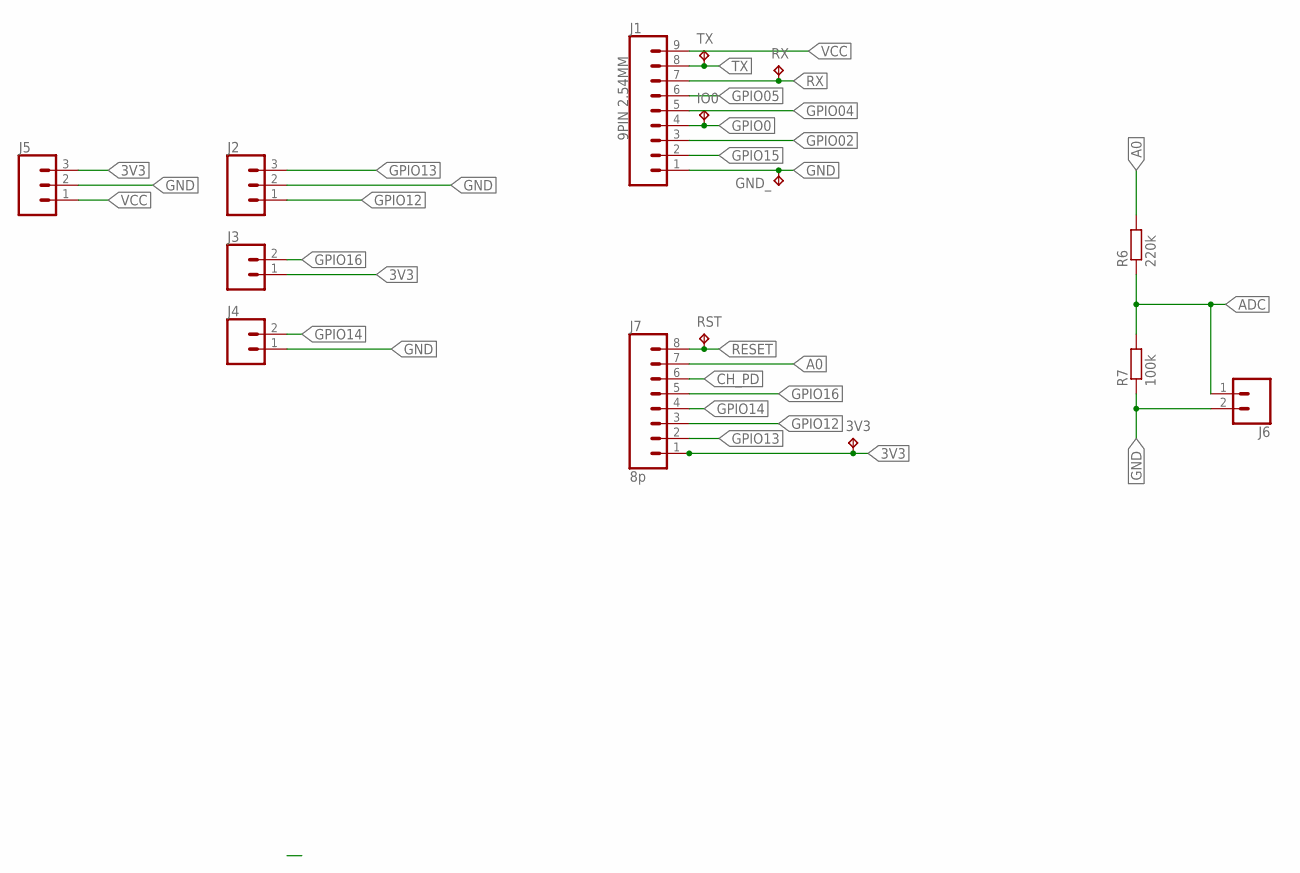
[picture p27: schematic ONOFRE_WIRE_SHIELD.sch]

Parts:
3V3: TPB1,27; B1,27
GND_: TPB1,27; B1,27
IO0: TPB1,27; B1,27
J1: 9PIN 2.54MM; 1X09
J2, J5: CONN_03; 1X03
J3, J4, J6: CONN_02; 1X02
J7: 8p; 1X08
R6: 220k; R0603
R7: 100k; R0603
RST: TPB1,27; B1,27
RX: TPB1,27; B1,27
TX: TPB1,27; B1,27

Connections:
3V3: 3V3.TP, J3.1, J5.3, J7.1
A0: J7.7, R6.2
ADC: J6.1, R6.1, R7.2
CH_PD: J7.6
GND: GND_.TP, J1.1, J2.2, J4.1, J5.2, J6.2, R7.1
GPIO0: IO0.TP, J1.4
GPIO02: J1.3
GPIO04: J1.5
GPIO05: J1.6
GPIO12: J2.1, J7.3
GPIO13: J2.3, J7.2
GPIO14: J4.2, J7.4
GPIO15: J1.2
GPIO16: J3.2, J7.5
RESET: J7.8, RST.TP
RX: J1.7, RX.TP
TX: J1.8, TX.TP
VCC: J1.9, J5.1

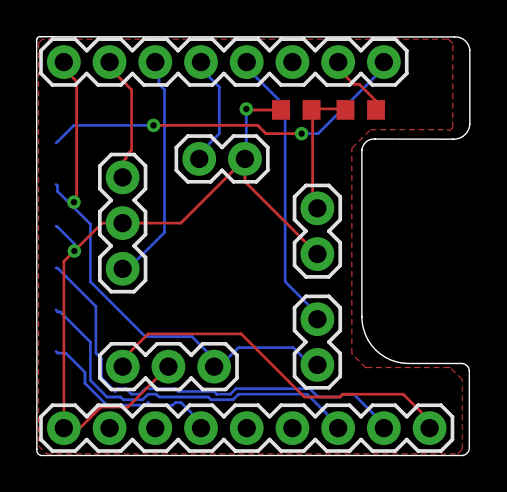
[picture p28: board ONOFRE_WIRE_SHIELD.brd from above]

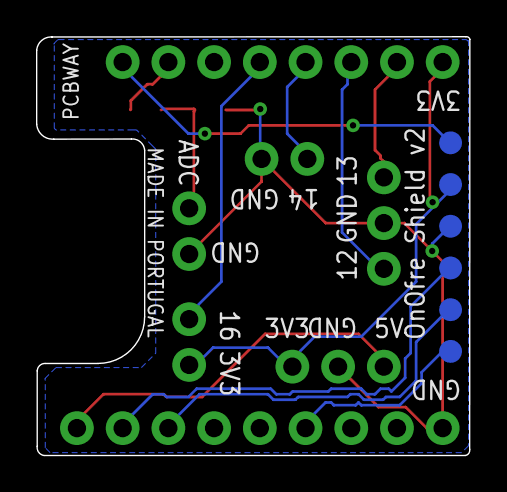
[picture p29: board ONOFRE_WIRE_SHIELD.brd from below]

Board: 2 copper layers, 24.1 x 23.3 mm, 15 parts (6 on the bottom side), 13 nets.

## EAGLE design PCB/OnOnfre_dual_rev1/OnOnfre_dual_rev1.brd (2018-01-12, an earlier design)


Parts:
C4: 100nF; 0603
D3: 1N4004; DO-214AC
F1: FUSE 2A; PTH
FLASH: B3U-1000P-2P-SMD; SW2-2.6-3.0X2.5X1.2+0.4MM
J1: 4p; SCREWTERMINAL-3.5MM-4
J6, J7: 8p; 1X08
K1, K2: OMRON-G3MB-202P-SSR2; OMRON-G3MB-202P-SSR
Q1, Q2: S8050; SOT23
R1, R2, R3, R4, R8, R9, R10, R11: 10k; R0603
RESET: B3U-1000P-2P-SMD; SW2-2.6-3.0X2.5X1.2+0.4MM
U1: LM1117; SOT223
U2: esp12; ESP12-SMD
U$2: HLK-PM03

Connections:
3V3: C4.1, J7.1, R8.2, R9.2, R10.2, U1.2 (OUT), U2.VCC
ADC: J7.7, U2.ADC
CH_PD: J7.6, R9.1, U2.CH_PD
FASE: J1.3, U$2.AC2
GND: C4.2, FLASH.2, J6.1, Q1.2 (E), Q2.2 (E), R2.1, R3.1, R11.2, RESET.2, U1.1 (ADJ), U2.GND, U$2.-VO
GPIO0: FLASH.1, J6.4, R8.1, U2.GPIO0
GPIO02: J6.3, U2.GPIO2
GPIO04: J6.6, R1.1, U2.GPIO4
GPIO05: J6.5, R4.1, U2.GPIO5
GPIO12: J7.3, U2.GPIO12
GPIO13: J7.2, U2.GPIO13
GPIO14: J7.4, U2.GPIO14
GPIO15: J6.2, R11.1, U2.GPIO15
GPIO16: J7.5, U2.GPIO16
unnamed: K1.4 (K), Q1.3 (C)
unnamed: D3.2 (-), K1.3 (A), K2.3 (A)
unnamed: Q1.1 (B), R3.2, R4.2
unnamed: K2.4 (K), Q2.3 (C)
unnamed: Q2.1 (B), R1.2, R2.2
NEUTRAL_IN: F1.P$1 (1), J1.4, U$2.AC1
NEUTRAL_IN_FUSED: F1.P$2 (2), K1.2 (DS2), K2.2 (DS2)
NEUTRAL_ONE_OUT: J1.2, K1.1 (DS1)
NEUTRAL_TWO_OUT: J1.1, K2.1 (DS1)
RESET: J7.8, R10.1, RESET.1, U2.RESET
RX: J6.7, U2.RXD0 (RX)
TX: J6.8, U2.TXD0 (TX)
VCC: D3.1 (+), U1.3 (IN), U$2.+VO

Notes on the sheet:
HLK-PM05
BH ON OFRE 12
ESP8266-12
REV1



Board: 2 copper layers, 53.0 x 55.0 mm, 23 parts (3 on the bottom side), 27 nets.

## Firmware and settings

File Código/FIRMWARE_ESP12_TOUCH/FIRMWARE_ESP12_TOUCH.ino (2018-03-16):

/**
 * Desenvolvido por Bruno Horta
 * 
 * Todo o código é livre e pode ser utilizado ou alterado
 * 
 * Exemplo: https://www.youtube.com/watch?v=OyY4ymv6db0
 * */
// Include the Bounce2 library found here :
// https://github.com/thomasfredericks/Bounce2
#include <Bounce2.h>
//MQTT
#include <PubSubClient.h>
//ESP
#include <ESP8266WiFi.h>'
//Wi-Fi Manger library
#include <DNSServer.h>
#include <ESP8266WebServer.h>
#include <WiFiManager.h>//https://github.com/tzapu/WiFiManager
//OTA
#include <WiFiUdp.h>
#include <ArduinoOTA.h>            
#define AP_TIMEOUT 180
#define SERIAL_BAUDRATE 115200
#define MQTT_AUTH false
#define MQTT_USERNAME ""
#define MQTT_PASSWORD ""
#define RELAY_ONE 5
#define RELAY_TWO 4
#define PAYLOAD_ON "ON"
#define PAYLOAD_OFF "OFF"
#define TOUCH_ONE 12
#define TOUCH_TWO 13
//CONSTANTS
const String HOSTNAME  = "OnOfreDual";
const char * OTA_PASSWORD  = "otapower";
const String MQTT_LOG = "system/log";
const String MQTT_SYSTEM_CONTROL_TOPIC = "system/set/"+HOSTNAME;
const String MQTT_LIGHT_ONE_TOPIC = "relay/one/set";
const String MQTT_LIGHT_TWO_TOPIC = "relay/two/set";
const String MQTT_LIGHT_ONE_STATE_TOPIC = "relay/one";
const String MQTT_LIGHT_TWO_STATE_TOPIC = "relay/two";
//MQTT BROKERS GRATUITOS PARA TESTES https://github.com/mqtt/mqtt.github.io/wiki/public_brokers
const char* MQTT_SERVER = "192.168.187.23";

WiFiClient wclient;
PubSubClient client(MQTT_SERVER,1883,wclient);

//CONTROL FLAGS
bool OTA = false;
bool OTABegin = false;
bool lastButtonOneState = false;
bool lastButtonTwoState = false;
bool lastButtonThreeState = false;


Bounce debouncer1 = Bounce(); 
Bounce debouncer2 = Bounce(); 

void setup() {
  Serial.begin(SERIAL_BAUDRATE);
  WiFiManager wifiManager;
  //reset saved settings
  //wifiManager.resetSettings();
  /*define o tempo limite até o portal de configuração ficar novamente inátivo,
   útil para quando alteramos a password do AP*/
  wifiManager.setTimeout(AP_TIMEOUT);
  if(!wifiManager.autoConnect(HOSTNAME.c_str())) {
    Serial.println("failed to connect and hit timeout");
    delay(3000);
    ESP.restart();
    delay(5000);
  } 
  client.setCallback(callback);
  pinMode(RELAY_ONE,OUTPUT);
  pinMode(RELAY_TWO,OUTPUT);
  // Setup the first button with an internal pull-up :
  pinMode(TOUCH_ONE,INPUT_PULLUP);
  // After setting up the button, setup the Bounce instance :
  debouncer1.attach(TOUCH_ONE);
  debouncer1.interval(5); // interval in ms
  
   // Setup the second button with an internal pull-up :
  pinMode(TOUCH_TWO,INPUT_PULLUP);
  // After setting up the button, setup the Bounce instance :
  debouncer2.attach(TOUCH_TWO);
  debouncer2.interval(5); // interval in ms
}

//LIGA O RELAY ONE e envia o estado ON por MQTT
void turnOnOne(){
  digitalWrite(RELAY_ONE,HIGH);
  if (checkMqttConnection()){
    client.publish(MQTT_LIGHT_ONE_STATE_TOPIC.c_str(),PAYLOAD_ON,true);
  }
}

//DESLIGA O RELAY ONE e envia o estado OFF por MQTT
void turnOffOne(){
  digitalWrite(RELAY_ONE,LOW);
  if (checkMqttConnection()){  
    client.publish(MQTT_LIGHT_ONE_STATE_TOPIC.c_str(),PAYLOAD_OFF,true);
  }
}

//LIGA O RELAY TWO e envia o estado ON por MQTT
void turnOnTwo(){
  digitalWrite(RELAY_TWO,HIGH);
  if (checkMqttConnection()){
    client.publish(MQTT_LIGHT_TWO_STATE_TOPIC.c_str(),PAYLOAD_ON,true);
  }
}

//DESLIGA O RELAY TWO e envia o estado OFF por MQTT
void turnOffTwo(){
  digitalWrite(RELAY_TWO,LOW);
  if (checkMqttConnection()){  
    client.publish(MQTT_LIGHT_TWO_STATE_TOPIC.c_str(),PAYLOAD_OFF,true);
  }
}

//Inverte o Estado do RELAY ON (ex: se ele estiver ligado então desliga e vice versa)
void toggleSwitchOne() {
  if(digitalRead(RELAY_ONE)){
   turnOffOne();
  }else{
   turnOnOne();
  }  
}

//Inverte o Estado do RELAY TWO (ex: se ele estiver ligado então desliga e vice versa)
void toggleSwitchTwo() {
  if(digitalRead(RELAY_TWO)){
   turnOffTwo();
  }else{
   turnOnTwo();
  }  
}

//Chamada de recepção de mensagens MQTT
void callback(char* topic, byte* payload, unsigned int length) {
  String payloadStr = "";
  for (int i=0; i<length; i++) {
    payloadStr += (char)payload[i];
  }
  Serial.println(payloadStr);
  String topicStr = String(topic);
  if(topicStr.equals(MQTT_SYSTEM_CONTROL_TOPIC)){
    if(payloadStr.equals("OTA_ON_"+String(HOSTNAME))){
      OTA = true;
      OTABegin = true;
    }else if (payloadStr.equals("OTA_OFF_"+String(HOSTNAME))){
      OTA = true;
      OTABegin = true;
    }else if (payloadStr.equals("REBOOT_"+String(HOSTNAME))){
      ESP.restart();
    }
  } else if(topicStr.equals(MQTT_LIGHT_ONE_TOPIC)){
    if(payloadStr.equals(PAYLOAD_ON)){
      turnOnOne();
    }else if(payloadStr.equals(PAYLOAD_OFF)) {
      turnOffOne();
    }
  }else if(topicStr.equals(MQTT_LIGHT_TWO_TOPIC)){
    if(payloadStr.equals(PAYLOAD_ON)){
      turnOnTwo();
    }else if(payloadStr.equals(PAYLOAD_OFF)) {
      turnOffTwo();
    }
  }
}

//Verifica se a ligação está ativa, caso não este liga-se e subscreve aos tópicos de interesse
bool checkMqttConnection(){
  if (!client.connected()) {
    if (MQTT_AUTH ? client.connect(HOSTNAME.c_str(),MQTT_USERNAME, MQTT_PASSWORD) : client.connect(HOSTNAME.c_str())) {
      //SUBSCRIÇÃO DE TOPICOS
      Serial.println("CONNECTED ON MQTT");
      client.subscribe(MQTT_SYSTEM_CONTROL_TOPIC.c_str());
      client.subscribe(MQTT_LIGHT_ONE_TOPIC.c_str());
      client.subscribe(MQTT_LIGHT_TWO_TOPIC.c_str());
      //Envia uma mensagem por MQTT para o tópico de log a informar que está ligado
      client.publish(MQTT_LOG.c_str(),(String(HOSTNAME)+" CONNECTED").c_str());
    }
  }
  return client.connected();
}

void loop() {
  debouncer1.update();
  debouncer2.update();
  bool realOneState = debouncer1.read();
  if(lastButtonOneState != realOneState ){
    lastButtonOneState = realOneState;
    if(realOneState){
    toggleSwitchOne();
    }
  }
  bool realTwoState = debouncer2.read();
  if(lastButtonTwoState != realTwoState  ){
    lastButtonTwoState = realTwoState;
     if(realTwoState){
    toggleSwitchTwo();
     }
  }

  
  if (WiFi.status() == WL_CONNECTED) {
    if (checkMqttConnection()){

      client.loop();
      if(OTA){
        if(OTABegin){
          setupOTA();
          OTABegin= false;
        }
        ArduinoOTA.handle();
      }
    }
  }
}


//Setup do OTA para permitir updates de Firmware via Wi-Fi
void setupOTA(){
  if (WiFi.status() == WL_CONNECTED && checkMqttConnection()) {
    client.publish(MQTT_LOG.c_str(),(String(HOSTNAME)+" OTA IS SETUP").c_str());
    ArduinoOTA.setHostname(HOSTNAME.c_str());
    ArduinoOTA.setPassword((const char *)OTA_PASSWORD);
    ArduinoOTA.begin();
    client.publish(MQTT_LOG.c_str(),(String(HOSTNAME)+" OTA IS READY").c_str());
  }  
}

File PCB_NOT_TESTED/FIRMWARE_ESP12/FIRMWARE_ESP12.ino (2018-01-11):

/**
 * Desenvolvido por Bruno Horta
 * 
 * Todo o código é livre e pode ser utilizado ou alterado
 * 
 * Exemplo: https://www.youtube.com/watch?v=OyY4ymv6db0
 * */
//MQTT
#include <PubSubClient.h>
//ESP
#include <ESP8266WiFi.h>'
//Wi-Fi Manger library
#include <DNSServer.h>
#include <ESP8266WebServer.h>
#include <WiFiManager.h>//https://github.com/tzapu/WiFiManager
//OTA
#include <WiFiUdp.h>
#include <ArduinoOTA.h>            
#define AP_TIMEOUT 180
#define SERIAL_BAUDRATE 115200
#define MQTT_AUTH false
#define MQTT_USERNAME ""
#define MQTT_PASSWORD ""
#define RELAY_ONE D5
#define RELAY_TWO D4
#define TOUCH 16
//CONSTANTS
const String HOSTNAME  = "OnOfreDual";
const char * OTA_PASSWORD  = "otapower";
const String MQTT_LOG = "system/log/"+HOSTNAME;
const String MQTT_SYSTEM_CONTROL_TOPIC = "system/set/"+HOSTNAME;
const String MQTT_LIGHT_ONE_TOPIC = "livingroom/light1/table2/set";
const String MQTT_LIGHT_TWO_TOPIC = "livingroom/light2/table2/set";
const String MQTT_LIGHT_ONE_STATE_TOPIC = "livingroom/light1/table2";
const String MQTT_LIGHT_TWO_STATE_TOPIC = "livingroom/light2/table2";
//MQTT BROKERS GRATUITOS PARA TESTES https://github.com/mqtt/mqtt.github.io/wiki/public_brokers
const char* MQTT_SERVER = "ip_dns_broker";

WiFiClient wclient;
PubSubClient client(MQTT_SERVER,1883,wclient);

//CONTROL FLAGS
bool OTA = false;
bool OTABegin = false;
bool lastButtonState = false;


void setup() {
  Serial.begin(SERIAL_BAUDRATE);
  WiFiManager wifiManager;
  //reset saved settings
  //wifiManager.resetSettings();
  /*define o tempo limite até o portal de configuração ficar novamente inátivo,
   útil para quando alteramos a password do AP*/
  wifiManager.setTimeout(AP_TIMEOUT);
  if(!wifiManager.autoConnect(HOSTNAME.c_str())) {
    Serial.println("failed to connect and hit timeout");
    delay(3000);
    ESP.restart();
    delay(5000);
  } 
  client.setCallback(callback);
  pinMode(RELAY_ONE,OUTPUT);
  pinMode(RELAY_TWO,OUTPUT);
  pinMode(TOUCH,INPUT); 
}
void turnOn1(){
  digitalWrite(RELAY_ONE,HIGH);
  client.publish(MQTT_LIGHT_ONE_STATE_TOPIC.c_str(),"ON");

}



void turnOff1(){
   digitalWrite(RELAY_ONE,LOW);  
   client.publish(MQTT_LIGHT_ONE_STATE_TOPIC.c_str(),"OFF");

}

void turnOn2(){
  digitalWrite(RELAY_TWO,HIGH);
  client.publish(MQTT_LIGHT_TWO_STATE_TOPIC.c_str(),"ON");

}



void turnOff2(){
   digitalWrite(RELAY_TWO,LOW);  
   client.publish(MQTT_LIGHT_TWO_STATE_TOPIC.c_str(),"OFF");

}
//Chamada de recepção de mensagem 
void callback(char* topic, byte* payload, unsigned int length) {
  String payloadStr = "";
  for (int i=0; i<length; i++) {
    payloadStr += (char)payload[i];
  }
  Serial.println(payloadStr);
  String topicStr = String(topic);
 if(topicStr.equals(MQTT_SYSTEM_CONTROL_TOPIC)){
  if(payloadStr.equals("OTA_ON")){
    OTA = true;
    OTABegin = true;
  }else if (payloadStr.equals("OTA_OFF")){
    OTA = true;
    OTABegin = true;
  }else if (payloadStr.equals("REBOOT")){
    ESP.restart();
  }
 } else if(topicStr.equals(MQTT_LIGHT_ONE_TOPIC)){
  Serial.println(payloadStr);
  if(payloadStr.equals("ON")){
  
      turnOn1();

    }else if(payloadStr.equals("OFF")) {
   
      turnOff1();

    }

  }else if(topicStr.equals(MQTT_LIGHT_TWO_TOPIC)){
  Serial.println(payloadStr);
  if(payloadStr.equals("ON")){
  
      turnOn2();

    }else if(payloadStr.equals("OFF")) {
   
      turnOff2();

    }

  }    
} 
void handleInterrupt() {
  if(digitalRead(RELAY_ONE)){
   turnOff1();
  }else{
   turnOn1();
  }  
}
bool checkMqttConnection(){
  if (!client.connected()) {
    if (MQTT_AUTH ? client.connect(HOSTNAME.c_str(),MQTT_USERNAME, MQTT_PASSWORD) : client.connect(HOSTNAME.c_str())) {
      //SUBSCRIÇÃO DE TOPICOS
      Serial.println("CONNECTED");
      client.subscribe(MQTT_SYSTEM_CONTROL_TOPIC.c_str());
      client.subscribe(MQTT_LIGHT_ONE_TOPIC.c_str());
      client.subscribe(MQTT_LIGHT_TWO_TOPIC.c_str());
    }
  }
  return client.connected();
}

void loop() {
  if (WiFi.status() == WL_CONNECTED) {
    if (checkMqttConnection()){
    bool realState = digitalRead(TOUCH);
      if(lastButtonState != realState){
        handleInterrupt();
        lastButtonState = realState;
      }
      client.loop();
      if(OTA){
        if(OTABegin){
          setupOTA();
          OTABegin= false;
        }
        ArduinoOTA.handle();
      }
    }
  }
}

void setupOTA(){
  if (WiFi.status() == WL_CONNECTED && checkMqttConnection()) {
    client.publish(MQTT_LOG.c_str(),"OTA SETUP ON");
    ArduinoOTA.setHostname(HOSTNAME.c_str());
    ArduinoOTA.setPassword((const char *)OTA_PASSWORD);
    
    ArduinoOTA.onStart([]() {
    client.publish(MQTT_LOG.c_str(),"START");
  });
  ArduinoOTA.onEnd([]() {
    client.publish(MQTT_LOG.c_str(),"END");
  });
  ArduinoOTA.onProgress([](unsigned int progress, unsigned int total) {
    String p = "Progress: "+ String( (progress / (total / 100)));
    client.publish(MQTT_LOG.c_str(),p.c_str());
  });
  ArduinoOTA.onError([](ota_error_t error) {
    if (error == OTA_AUTH_ERROR) client.publish(MQTT_LOG.c_str(),"Auth Failed");
    else if (error == OTA_BEGIN_ERROR)client.publish(MQTT_LOG.c_str(),"Auth Failed"); 
    else if (error == OTA_CONNECT_ERROR)client.publish(MQTT_LOG.c_str(),"Connect Failed");
    else if (error == OTA_RECEIVE_ERROR)client.publish(MQTT_LOG.c_str(),"Receive Failed");
    else if (error == OTA_END_ERROR)client.publish(MQTT_LOG.c_str(),"End Failed"); 
  });
 ArduinoOTA.begin();
 }  
}

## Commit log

2017-12-25 Organização de ficheiros e versões do OnOfre, devenvolvimento da dev board
    [BHONoff.brd, BHONoff.sch, BHOnOfreDevBoard.brd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]
2017-12-25 Header pins para ligar os relés
    [BHOnOfreDevBoard.brd, BHOnOfreDevBoard.sch]
2017-12-25 melhoramentos nas pistas da dev board
    [BHOnOfreDevBoard.brd, BHOnOfreDevBoard.sch]
2017-12-26 ficheiros para fazer a PCB na CNC
    [BHOnOfreDevBoard.brd]
2017-12-29 problema de pull up dos relés resolvido, alteração da fonte de 3.3v para 5v
    [BHOnOfreDevBoard.brd, BHOnOfreDevBoard.sch]
2018-01-05 nova board
    [BHOnOfreBoard.brd, BHOnOfreBoard.sch]
2018-01-07 Versão Square em DEV
    [BHOnOfreSquareBoard.brd, BHOnOfreSquareBoard.sch]
2018-01-11 fix relay position
    [BHOnOfreBoard.brd]
2018-01-11 organização de PCB testadas , não testadas e em desenvolvimento
    [BHOnOfreBoard.brd, BHOnOfreBoard.sch, BHOnOfreDevBoard.brd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]
2018-01-12 OnOfre Square rev2 80% pronto
    [BHOnOfreBoard.brd, BHOnOfreSquareBoard.brd, BHOnOfreSquareBoard.sch]
2018-01-13 Square Rev2 pronto para testes
    [BHOnOfreSquareBoard.brd, BHOnOfreSquareBoard.sch]
2018-01-15 versão 3 com sensor de corrente, permite medir consumos
    [BHOnOfreSquareBoardCurrentSensor.brd, BHOnOfreSquareBoardCurrentSensor.sch]
2018-01-16 REV1 teste OK demo em https://youtu.be/ygMf2j0tS-s
    [BHOnOfreBoard.brd, BHOnOfreBoard.sch, BHOnOfreSquareBoardCurrentSensor.brd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]
2018-01-20 change switch place
    [BHOnOfreSquareBoard.brd, BHOnOfreSquareBoardCurrentSensor.brd, BHOnOfreSquareBoardCurrentSensor.sch]
2018-01-20 fix labels, gerber files
    [BHOnOfreSquareBoard.brd]
2018-02-17 Organização do repositorio
    [BHOnOfreDevBoard.sch, BHOnOfreESP01.brd, BHOnOfreESP01.sch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]
2018-03-05 Rev3.1 dual
    [OnOfre_2ADSP.brd, OnOfre_2ADSP.sch, OnOnfre_dual_rev2.brd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]
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2018-03-21 3.2 Via por baixo do ESP8266 mudada de sitio
    [OnOfre_2ADSP.brd, OnOfre_2ADSP.sch]
2018-04-03 resolvido a troca na label dos pinos 04 e 05
    [OnOnfre_dual_mola_ssr_rev3.2.brd, OnOnfre_dual_mola_ssr_rev3.2.sch, OnOnfre_dual_parafuso_ssr_rev3.2.brd]
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2018-04-11 Rev 3.4, alteração de labels e numero de pinos
    [OnOnfre_dual_mola_ssr_rev3.4.brd, OnOnfre_dual_mola_ssr_rev3.4.sch, OnOnfre_dual_parafuso_ssr_rev3.2.brd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]
2018-04-19 nova versão OnOfre Parafuso com 2 relés de estado sólido
    [OnOnfre_dual_parafuso_ssr_rev3.4.brd, OnOnfre_dual_parafuso_ssr_rev3.4.sch]
2018-04-27 estores e tomada em progresso
    [OnOnfre_dual_parafuso_estores_beta.brd, OnOnfre_dual_parafuso_estores_beta.sch]
2018-05-05 Novo Firmware
    [OnOnfre_dual_parafuso_ssr_rev3.4.brd]
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2018-05-09 Labels Fix
    [OnOnfre_dual_parafuso_ssr_rev3.4.brd, OnOnfre_dual_parafuso_ssr_rev3.4.csv, OnOnfre_plug_dev_nao_usar.brd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]
2018-05-22 remoção do OTA Arduino e adição de OTA via Web
    [OnOnfre_dual_parafuso_estores_beta.brd, OnOnfre_dual_parafuso_estores_beta.sch, OnOnfre_plug_dev_nao_usar.brd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]
2018-06-21 pdf com esquema
    [OnOnfre_dual_parafuso_estores_beta.brd]
2018-07-14 Rev3.5 Parafuso
    [OnOnfre_dual_parafuso_estores_beta.brd, OnOnfre_dual_parafuso_estores_beta.sch]
2018-08-31 Alteração de Nomes de Boards
    [OnOnfre_EasyBlinds_rev1.brd, OnOnfre_EasyBlinds_rev1.sch, OnOnfre_Easy_Light_rev1.brd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]
2018-08-31 Organização de Boards
    [OnOfre_EasyPlug_dev.brd, OnOfre_EasyPlug_dev.sch, OnOnfre_EasyBlinds_beta2.brd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]
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2018-09-20 versão beta 1
    [OnOnfre_Easy_Light_dev.brd, OnOnfre_Easy_Light_dev.sch]
2018-09-21 easy light board
    [OnOnfre_Easy_Light_dev.brd, OnOnfre_Easy_Light_dev.sch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]
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2018-10-01 versão 1.5
    Correcção do BUG no topico dos sensores de temperatura.
    Adição de suporte e migração entre diferentes versões de firmware
2018-10-02 Bug Fix
    nao desliga o AP depois de configurado o Wi-FI - Resolvido
    remoção do "a" perdido
    update da config apos alteração do nome do NÓ
    update do mDNS apois alteraçao do nome do NÓ
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2018-10-11 V1.60 Suporte para DS18B20, configuração de IP Fixo, Configuração de Nome de funcionalidade de cada sensor, ex temperatura
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2018-10-14 Correcção de BUG na edição do Nome da função do sensor Humidade
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2018-10-21 board
    board
    [OnOnfre_Easy_Light_dev.brd]
2018-11-01 Revert "rev5.0dev"
    This reverts commit 2e2358a8c57761c3fa030a0a65c911856fe9a90b.
    [OnOnfre_DevBoard.brd, OnOnfre_DevBoard.sch]
2018-11-01 Revert "Revert "rev5.0dev""
    This reverts commit b527e27402ec8f63df68f9227db4901d182b5901.
    [OnOnfre_DevBoard.brd]
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2018-11-10 fix switch
2018-11-10 Firmware 2.1
    Possibilidade de adicionar mais Swichs Fisicos ou virtuais
    Possibilidade de adicionar mais relés
    BUG FIX - Perda dos Swiths gravados
    BUG FIX - Memoria de estado invalido com o MQTT
    [OnOfre_EasyPlug_dev.brd, OnOfre_EasyPlug_dev.sch, OnOnfre_DevBoard.brd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]
2018-11-12 correcção de bug ao adicionar relés
    [OnOnfre_DevBoard.brd, OnOnfre_DevBoard.sch, OnOnfre_DevBoard_rev4.brd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]
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2018-11-14 Versão 2.7 resolução do bug na publicação de estado dos estores via MQTT
2018-11-15 correcção do bug de State Position na integração do home assistant com o tipo Cover
2018-11-15 Versão 2.9 BUG FIX: correcção de Abertura ou Fecho de estore caso o sistema reinicie
2018-11-16 Passagem do Firmware para novo Repo https://github.com/brunohorta82/BH-Easy-Iot
    [OnOnfre_DevBoard.brd, OnOnfre_DevBoard.sch, OnOnfre_DevBoard_rev4.brd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]
2018-11-16 caixas e adaptadores
    [3D Printed BH Casing Livolo - Casing.stl, 3D Printed BH Casing Livolo- Plate.stl, Onofre Protecção.stl]
2018-11-16 rev 5 in progress
    [OnOnfre_DevBoard_rev4.brd, OnOnfre_DevBoard_rev4.sch]
2018-12-13 beta2 board 5A
    [OnOnfre_DevBoard.brd, OnOnfre_DevBoard.sch, OnOnfre_DevBoard_rev4.brd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]
2018-12-14 REV5
    REV5 IN PROGRESS
    [OnOnfre_DevBoard_rev5.brd, OnOnfre_DevBoard_rev5.sch]
2018-12-14 rev 5
    [OnOnfre_DevBoard_rev5.brd]
2018-12-17 rev5 adc A0
    [OnOnfre_DevBoard_rev5.brd, OnOnfre_DevBoard_rev5.sch]
2018-12-18 rev1.0 single
    [PCB_OnOnfre_SINGLE_rev1.brd, PCB_OnOnfre_SINGLE_rev1.sch]
2018-12-20 pcb single
    [PCB_OnOnfre_SINGLE_rev1.brd]
2019-01-10 rev5.1
    remoção de diodos e slot para relés mecanicos
    [OnOnfre_DevBoard.brd, OnOnfre_DevBoard.sch, OnOnfre_DevBoard_rev5.brd]
2019-01-10 Revert "rev5.1"
    This reverts commit eb04db9ecb2416f00214f08c4929ad914bbcba1f.
    [OnOnfre_DevBoard.sch, OnOnfre_DevBoard_rev5.brd, OnOnfre_DevBoard_rev5.sch]
2019-01-10 Revert "sol"
    This reverts commit 5e2c5b42127c6a8382e434407ba92e7f1eb271ca.
    [OnOnfre_DevBoard.brd, OnOnfre_DevBoard.sch]
2019-01-18 Caixas Rev5
    [ONOFRE Bottom Cover REV5.stl, ONOFRE REV5.stl]
2019-04-18 shield wire
    [OnofreWireShield.brd, OnofreWireShield.sch]
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2019-06-06 REMOÇÃO DE PCB'S ANTIGAS E BETAS
    [OnOnfre_DevBoard.brd, OnOnfre_DevBoard.sch, OnOnfre_DevBoard_rev4.brd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]
2019-06-07 ADD NEW SLOT OVER N AND L
    [OnOnfre_DevBoard.brd]
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2019-07-07 Rename Folders, Alteração de nome de pastas
    Rename folders to support EN and PT
    Alteração de nome de pastas para EN e PT
    [ONOFRE_DUAL_LUZES_LIGHT_SSR_R5.1.brd, ONOFRE_DUAL_LUZES_LIGHT_SSR_R5.1.sch, ONOFRE_ESTORES_COVERS_R1.0.brd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]
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2019-08-27 update values Onofre Cover V1
    [ONOFRE_ESTORES_COVERS_R1.0.sch]
2020-01-11 Onofre Shields Dev and REV3
    [ONOFRE DEV SHIELD 3.0.brd, ONOFRE DEV SHIELD 3.0.sch, ONOFRE SWITCH SHIELD 3.0.brd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]
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

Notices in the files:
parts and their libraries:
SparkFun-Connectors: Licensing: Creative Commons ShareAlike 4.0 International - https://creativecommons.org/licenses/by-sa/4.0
